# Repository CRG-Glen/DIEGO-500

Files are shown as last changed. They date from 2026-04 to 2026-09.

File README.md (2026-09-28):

# DIEGO PROJECT

Turn your A500 into an A2000 with this sidecar backplane
CHECKMATE VERSION NOT YET TESTED - DO NOT BUILD

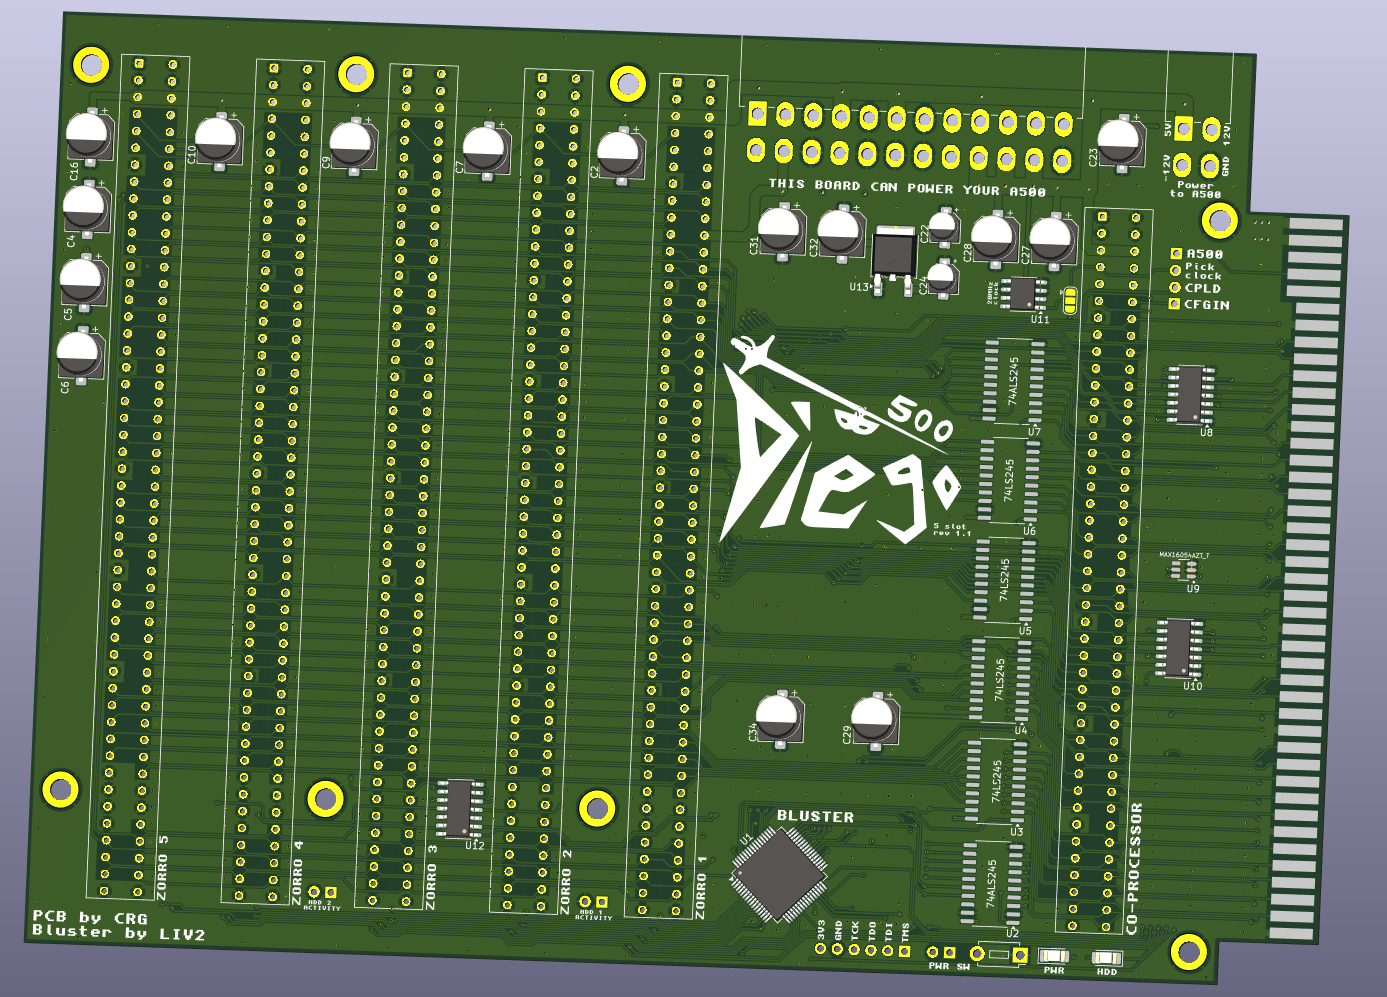
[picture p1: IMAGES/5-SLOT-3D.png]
PCB


## What's this?  

DIEGO is a Zorro 2 backplane expansion for use on your A500 either as a side car project or within your Checkmate case.  Diego gives you an A2000 compatible CO-PROCESSOR slot (side car version only) along with a full set of 5 ZORRO2 slots all made possible by the onboard Bluster IC.  Bluster is a remake of the classic A2000 Buster chip by LIV2 although it is a custom version for DIEGO to handle inverted clocks and provide some further functions.  

DIEGO has been tested extensively with various CPU and Zorro cards, a list of tested cards is provided below.  If you have anything to add to this list, please get in touch.  

DIEGO is also intended to power your A500 via the passthrough 4 pin connector adjacent to the main 24 pin ATX connector.  Please note that on the Checkmate version has power connected at the side car but also space for a passthrough.  The side car version currently does not have power connected at the side car.  For this version you must use the pass through to power your A500.  

## Ordering

There are currently 3 versions of DIEGO, a side car 5 slot version, a side car 3 slot version and a version for installation within a Checkmate case.  Please note that at present both the 3 slot and checkmate versions have not been tested so build at your own risk.  Checkmate version is currently in testing, I do not recommend building until it's confirmed working and ready.  

Gerber, BOM and CPL files are provided for each in the JLCPCB folder.  

All passives on each version are located on the bottom side (with exception of ferrite bead on checkmate version).  All logic and electrolytic caps are located on the top side.  

Each version of DIEGO is a 4 layer board.  HASL finish is fine for this project, inner layers can be left 0.5oz.  

All signals are routed on the top and bottom layers but there are some power traces on each internal layer along with solid grounds.  

Due to the amount of passives I recommend having your PCB manufacturer fit the bottom side, you then as builder complete the top side.  

While all components are available at JLC several top side parts are getting expensive!  

## Assembly

Assuming you got your boards made with the bottom side completed you may fit out the top side to suit yourself.  I recommend fitting and programming the CPLD first and finish all SMD work before doing the slots as they'll just get in the way!  

NOTE (side car version only): U11 is only required if you're using something in the COPROCESSOR slot that needs a 28mhz clock.  There doesn't seem to be that many (if any) cards that do require this so you may leave this off if you prefer. (this has not been tested as I don't have anything that needs this clock)

FURTHER NOTE: You MUST use LS and ALS logic as per the BOM.  DIEGO was originally built with HCT logic but this caused issues with several boards.  HCT will work if you prefer to use this but you might find some early SCSI cards don't work.  

For the 86pin slot to the A500 on the side car version you will need to bend the pins in to meet the pads on DIEGO.  

For programming the CPLD, the required JED file is available in the CPLD folder or you may get it from LIV2s GitHub.  I use a Raspberry PI to programme CPLDs as per LIV2s guide but use whatever method you're comfortable with.  Just remember if using a PI and if powering 3.3v from the PI, disconnect all other power supplies from DIEGO 500!

## Using your DIEGO

For the most part DIEGO is simply plug and play but there are a few things to keep in mind.
- Firstly there is a single jumper to configure to select which 7mhz clock to use.  If you're using a Rev3 or 5 A500 you must select CPLD clock.  If you're using a Rev6 A500 you can use either but if using A500 clock you need to close JP6 on the A500s motherboard.  If you are using an A500+ you can pick either.  The CPLD clock is derived from _CCK XNOR _CCQK within the CPLD.    
- There is one more pin header labelled CFGIN.  If you have any expansions in your A500 on the autoconfig chain you MUST connect said expansions config out to this config in.  If you don't you'll most likely get a yellow screen or just no zorro cards detected!
- Insert all cards as if this was a real A2000 i.e. the front of DIEGO is the front of an A2000.  Most modern Zorro expansions (especially half length cards) will have an arrow pointing to front or back.  Pay attention to this! If you plug something in wrong expect a dead card and possibly dead Amiga! 
- Zorro 2 cards will autoconfigure themselves just like they would in any Amiga.  To confirm this hold both mouse buttons on start up to access the early start-up menu and select "expansion board diagnostic" (only available to kickstart 2.04 and up)

Side car version only
-  If you're using a true A2000 CPU card in the COPROCESSOR slot (like the N2630) simply insert the card and Bluster will tristate the internal A500 CPU. (this is achieved by Bluster monitoring _BOSS and when asserted, Bluster asserts _BR to the internal CPU)  
- If you are using an A500 type accelerator in the COPROCESSOR slot such as TF536 or a PISTORM (including PISTORM 2000), you MUST open the A500 and remove the internal CPU.  Even if you manually assert _BOSS, the E clocks will clash and it won't work.  There is NO fix for this!  A2000 accelerators work as they monitor E and sync to it or generate it as necessary.  

Checkmate version only
- If you're using an accelerator in the A500s CPU socket you may need to connect its config out to the config in pin on DIEGO.  If you get a yellow screen or crash on boot this is the likely cause.  

## Testing and Results

With thanks to GADGETUK, SPARX, CATHERS and ANDI@HBR we've been able to test and confirm that most boards 
work fine in DIEGO.  The below table lists those boards tested and confirmed as working or not.

| Card Type | Name | Status |
|---|---|---|
| SCSI | Commodore A2090A | Working but very fussy (requires LS and ALS logic).  Only bluescsi V2 and only in raw mode. |
| SCSI | Commodore A2091 | Working |
| SCSI | GVP Series II HC+8 | Working |
| IDE |	Ripple IDE | Working |
| IDE |	AT-Bus clone | Working |
| IDE |	Buddha | Working |
| RAM |	Amigakit ZORRAM | Working |
| RAM |	Gottagofastram 2000 | Working |
| Sound | Prelude | Working |
| RTG |	GBAPII | Working |
| Multi-feature | LAN-IDE-Clock | Working/Working/Not tested |
| CPU |	A2630 | Working |
| CPU |	N2630 | Working |
| CPU |	TF520 | Working |
| CPU |	TF536 | Working |
| CPU |	TK2 | Working |
| CPU |	Pistorm | Working |
| CPU |	Pistorm 2k | Working |

If you can add to this table please get in touch!

## Case

At present there is no full case but there is a base that will hold either the 3 or 5 slot version of Diego level with the side car slot of your A500.  I'm not great at designing these things so if you want to help please get in touch.  STL files are in the BASE folder.  

## FAQ

Several people have asked about adding ISA slots, a video slot or making this remote with a ribbon cable to the A500.  

ISA slots - DIEGO side car has been designed so that you could in theory add ISA slots on a separate board, the Zorro slots 
in relation to the edge of the PCB are positioned to allow this.  I haven't designed an ISA slot extension as I don't have a bridge board to test it with.  
The Checkmate version could be redesigned to incorporate ISA slots although you will loose 2 of the half length zorro slots.  For this release it was thought more useful to include 5 zorro slots. 

Video slot - There are no plans to add a video slot.  Very few of the required signals are on the A500s side car so it would need a multicore ribbon from DENISE.  

Ribbon Cable for remote use - If you want to try a ribbon cable to have DIEGO remote from your 500 you can simply solder one onto the edge connector but I don't expect this to work without further buffering! (like in the bodega bay).

A1000 version - This is coming along with a rework of the entire project to sit vertical beside your 500.  It'll take a while to figure out so please bear with me.  

## License

This project represents countless hours of work by not just me but LIV2 and everyone involved in testing.  It is however released under a CERN Open Hardware Licence v2 for the community to enjoy.  

While I cannot put any direct stipulations into this I would ask that it should only be built and sold at cost plus time.  

If you plan on forking or using this as the basis for any other works you must comply with the following as per the terms of the license attributed to this project.
1. All attributions and credits as presented within this github and on the DIEGO 500 PCB must be maintained and carried through.
2. Any derivative of this project must be also be released open source.

If you are doing a build of these please consider a £1 donation per board to my kofi - https://ko-fi.com/crg_glen.  I'm at least £500 into this project so any support to recoup this is appreicated.  

## Credits

Based on A2000 rev6 schematics by Dave Haynie and EATX2000 by Jasonsbeer

PCB by CRG(Glen)

Bluster by LIV2

Artwork by Brick Studios

Testing by GadgetUK, Sparx, Cathers and Andi@HBR

Thanks to Mikerochip for inspiration for the PSU switch, Neil from Retro4U for loaning his GVP for testing and Kazanoz for helping with the BOM

Special thanks to GadgetUK for hosting the test room on his discord and LIV2 for his work modifying Bluster

Extra Special thanks to Rob Cranley and Steve Jones for their help on the Checkmate version

Why is it called Diego?  Well... this project started solely as a Zorro 2 expansion and to implement that I first had
to understand how the Zorro bus worked.  You might say I had to unmask Zorro.  The character of Zorro unmasked is called Don Diego so Diego 500 or Diego Checkmate.

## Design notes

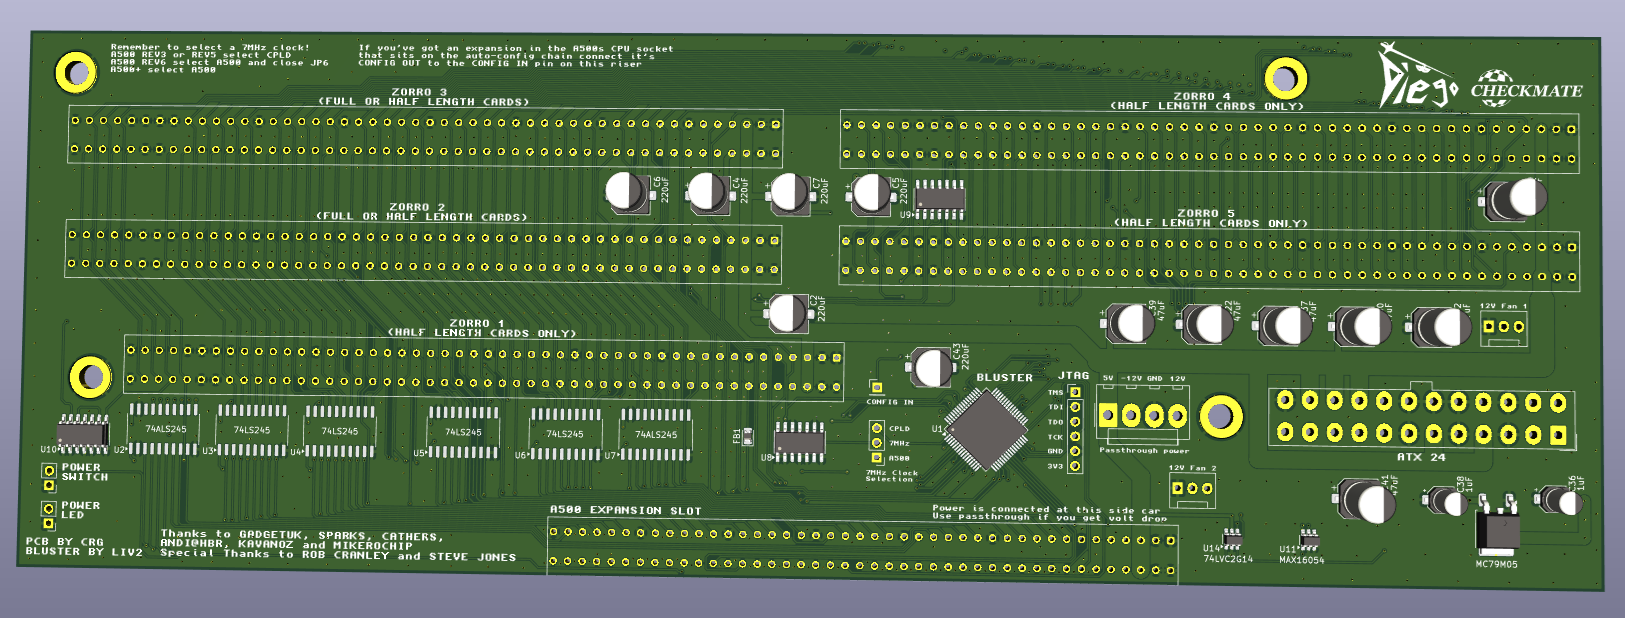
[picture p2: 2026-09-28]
JLCPCB/Checkmate/IMAGES/Checkmate-3D.png

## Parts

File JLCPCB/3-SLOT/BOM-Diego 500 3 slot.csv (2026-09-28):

Comment | Designator | Footprint | LCSC | Quantity
0.1uf | C1,C11,C12,C13,C14,C15,C17,C18,C19,C20,C21,C3,C30,C33,C8 | C_0805_2012Metric | C49678 | 15
1000pf | CN10,CN11,CN12,CN13,CN14,CN15,CN16,CN17,CN7,CN8,CN9 | R_Array_Convex_4x0603 | C541606 | 11
100pf | C25,C26 | C_0805_2012Metric | C1790 | 2
10k | R11,R12,R13,R18,R19,R20,R21,R22 | R_0805_2012Metric | C17414 | 8
1k | R1,R14,R17,R2,R24,R27,R28,R29,R38,R39,R40,R41,R5,R6 | R_0805_2012Metric | C17513 | 14
1k | RN1,RN10,RN11,RN12,RN13,RN14,RN15,RN16,RN17,RN18,RN19,RN2,RN20,RN8,RN9 | R_Array_Convex_4x0603 | C20197 | 15
1uF | C22,C24 | CP_Elec_4x5.4 | C3348 | 2
220uF | C2,C34,C4,C5,C6,C7,C9 | CP_Elec_6.3x7.7 | C278407 | 7
3.3k | RN3,RN4,RN5,RN6 | R_Array_Convex_4x0603 | C102665 | 4
3.3k | R10 | R_0805_2012Metric | C26010 | 1
33 | R3 | R_0805_2012Metric | C17634 | 1
4.7k | R25,R26,R7,R9 | R_0805_2012Metric | C17673 | 4
4.7k | RN7 | R_Array_Convex_4x0603 | C66697 | 1
47 | R16,R23,R4 | R_0805_2012Metric | C17714 | 3
47uF | C23,C27,C28,C29,C31,C32 | CP_Elec_6.3x7.7 | C336249 | 6
501MLFT | U11 | SOIC-8_3.9x4.9mm_P1.27mm | C2651221 | 1
680 | R15 | R_0805_2012Metric | C17798 | 1
74ALS245 | U2,U7 | SO-20_5.3x12.6mm_P1.27mm | C2675885 | 2
74LS08 | U10 | SO-14_3.9x8.65mm_P1.27mm | C6802 | 1
74LS245 | U3,U4,U5,U6 | SO-20_5.3x12.6mm_P1.27mm | C7753 | 4
74LS32 | U12,U8 | SO-14_3.9x8.65mm_P1.27mm | C116812 | 2
A2000_CPUSLOT_EDGE_LOGICAL | J2 | WingTAT ED86BGFBK | C5173317 | 1
BLUSTER | U1 | TQFP-64_10x10mm_P0.5mm | C90569 | 1
FerriteBead_Small | FB1 | D_0805_2012Metric 100ohm @ 100mhz | C15957 | 1
LED | D2 | LED_1206_3216Metric_Pad1.42x1.75mm_HandSolder | C14641 | 1
LED | D1 | LED_1206_3216Metric_Pad1.42x1.75mm_HandSolder | C49018 | 1
MAX16054AZT_T | U9 | SOT95P275X110-6N | C79401 | 1
MC79M05 | U13 | TO-252-2 | C126401 | 1
S8050 | Q1 | SOT-23 | C2146 | 1
Zorro 1 | CN2 | WingTAT ED100BGFBK | C5173320 | 1
Zorro 2 | CN3 | WingTAT ED100BGFBK | C5173320 | 1
Zorro 3 | CN4 | WingTAT ED100BGFBK | C5173320 | 1
Conn_01x01_Pin | J9 | PinHeader_1x01_P2.54mm_Vertical |  | 1
Power to A500 | J8 | Molex_Mini-Fit_Jr_5569-04A2_2x02_P4.20mm_Horizontal |  | 1
Conn_01x03_Pin | J1 | PinHeader_1x03_P2.54mm_Vertical |  | 1
Conn_01x02_Pin | J5 | PinHeader_1x02_P2.54mm_Vertical |  | 1
HDD 2 | J3 | PinHeader_1x02_P2.54mm_Vertical |  | 1
Buster | J7 | PinHeader_1x06_P2.54mm_Vertical |  | 1
A500 side car | CN1 | A500_SIDE_CONNECTOR |  | 1
ATX-24 | J6 | Molex_Mini-Fit_Jr_5569-24A2_2x12_P4.20mm_Horizontal |  | 1
SW_Push | SW1 | SW_PUSH_1P1T_6x3.5mm_H4.3_APEM_MJTP1243 |  | 1
HDD 1 | J4 | PinHeader_1x02_P2.54mm_Vertical |  | 1

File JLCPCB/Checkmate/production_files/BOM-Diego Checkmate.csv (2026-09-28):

Comment | Designator | Footprint | LCSC | Quantity
0.1uf | C1,C11,C12,C13,C14,C15,C16,C17,C18,C19,C20,C21,C3,C30,C35,C8,C9 | C_0805_2012Metric | C49678 | 17
1000pf | CN10,CN11,CN12,CN13,CN14,CN15,CN16,CN17,CN7,CN8,CN9 | R_Array_Convex_4x0603 | C541606 | 11
100pf | C25,C26 | C_0805_2012Metric | C1790 | 2
10k | R18,R19,R20,R21,R22,R3 | R_0805_2012Metric | C17414 | 6
1k | R1,R11,R12,R13,R14,R15,R17,R2,R24,R27,R28,R29,R30,R5,R6,R8 | R_0805_2012Metric | C17513 | 16
1k | RN1,RN10,RN11,RN12,RN13,RN14,RN15,RN16,RN17,RN18,RN19,RN2,RN8,RN9 | R_Array_Convex_4x0603 | C20197 | 14
1uF | C36,C38 | CP_Elec_4x5.4 | C3348 | 2
220uF | C10,C2,C4,C43,C5,C6,C7 | CP_Elec_6.3x7.7 | C278407 | 7
3.3k | R10 | R_0805_2012Metric | C26010 | 1
3.3k | RN3,RN4,RN5,RN6 | R_Array_Convex_4x0603 | C425215 | 4
4.7k | R25,R26,R7,R9 | R_0805_2012Metric | C17673 | 4
4.7k | RN7 | R_Array_Convex_4x0603 | C66697 | 1
47 | R16,R23,R4 | R_0805_2012Metric | C17714 | 3
47uF | C22,C37,C39,C40,C41,C42 | CP_Elec_6.3x7.7 | C336249 | 6
74ALS245 | U2,U7 | SO-20_5.3x12.6mm_P1.27mm | C2675885 | 2
74LS08 | U10 | SO-14_3.9x8.65mm_P1.27mm | C6802 | 1
74LS245 | U3,U4,U5,U6 | SO-20_5.3x12.6mm_P1.27mm | C7753 | 4
74LS32 | U8,U9 | SO-14_3.9x8.65mm_P1.27mm | C116812 | 2
74LVC2G14 | U14 | SOT-23-6 | C12401 | 1
A500 side car | CN1 | Samtec_HLE-150-02-xx-DV-TE_2x43_P2.54mm_Horizontal | C5173317 | 1
BLUSTER | U1 | TQFP-64_10x10mm_P0.5mm | C90569 | 1
FerriteBead_Small | FB1 | D_0805_2012Metric | C1015 | 1
MAX16054 | U11 | SOT-23-6 | C79401 | 1
MC79M05 | U15 | TO-252-2 | C126401 | 1
S8050 | Q2,Q3,Q4 | SOT-23 | C2146 | 3
Zorro 1 | CN2 | Samtec_HLE-150-02-xx-DV-TE_2x50_P2.54mm_Horizontal | C5173320 | 1
Zorro 2 | CN3 | Samtec_HLE-150-02-xx-DV-TE_2x50_P2.54mm_Horizontal | C5173320 | 1
Zorro 3 | CN4 | Samtec_HLE-150-02-xx-DV-TE_2x50_P2.54mm_Horizontal | C5173320 | 1
Zorro 4 | CN5 | Samtec_HLE-150-02-xx-DV-TE_2x50_P2.54mm_Horizontal | C5173320 | 1
Zorro 5 | CN6 | Samtec_HLE-150-02-xx-DV-TE_2x50_P2.54mm_Horizontal | C5173320 | 1
Power LED | J4 | PinHeader_1x02_P2.54mm_Vertical |  | 1
Conn_01x04 | J2 | Molex_KK-396_A-41791-0004_1x04_P3.96mm_Vertical |  | 1
Fan 2 | M2 | FanPinHeader_1x03_P2.54mm_Vertical |  | 1
Conn_01x02_Pin | J3 | PinHeader_1x02_P2.54mm_Vertical |  | 1
ATX-24 | J10 | Molex_Mini-Fit_Jr_5566-24A_2x12_P4.20mm_Vertical |  | 1
Buster | J7 | PinHeader_1x06_P2.54mm_Vertical |  | 1
Conn_01x03_Pin | J1 | PinHeader_1x03_P2.54mm_Vertical |  | 1
Conn_01x01_Pin | J9 | PinHeader_1x01_P2.54mm_Vertical |  | 1
Fan 1 | M1 | FanPinHeader_1x03_P2.54mm_Vertical |  | 1

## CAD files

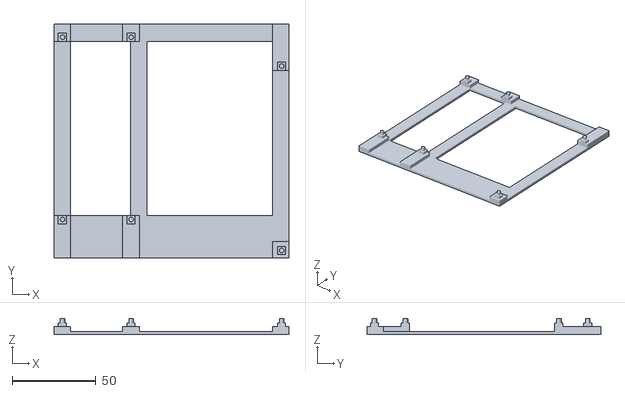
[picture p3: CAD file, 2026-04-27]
BASE/Diego 500 3 slot base.stl
140.5 x 140.0 x 9.75

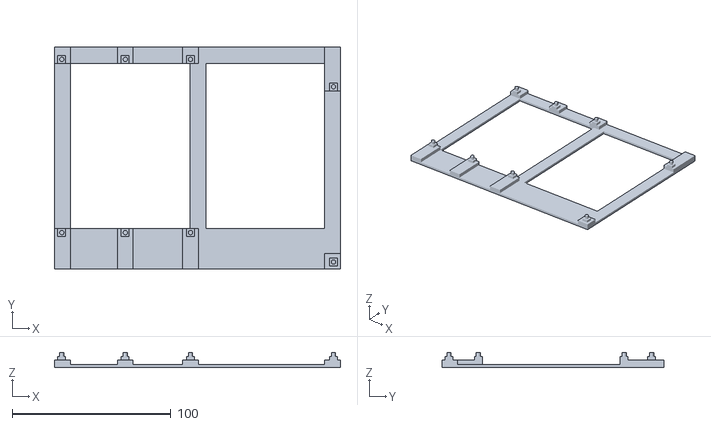
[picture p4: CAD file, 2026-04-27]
BASE/Diego 500 5 slot base.stl
180.0 x 140.0 x 9.75

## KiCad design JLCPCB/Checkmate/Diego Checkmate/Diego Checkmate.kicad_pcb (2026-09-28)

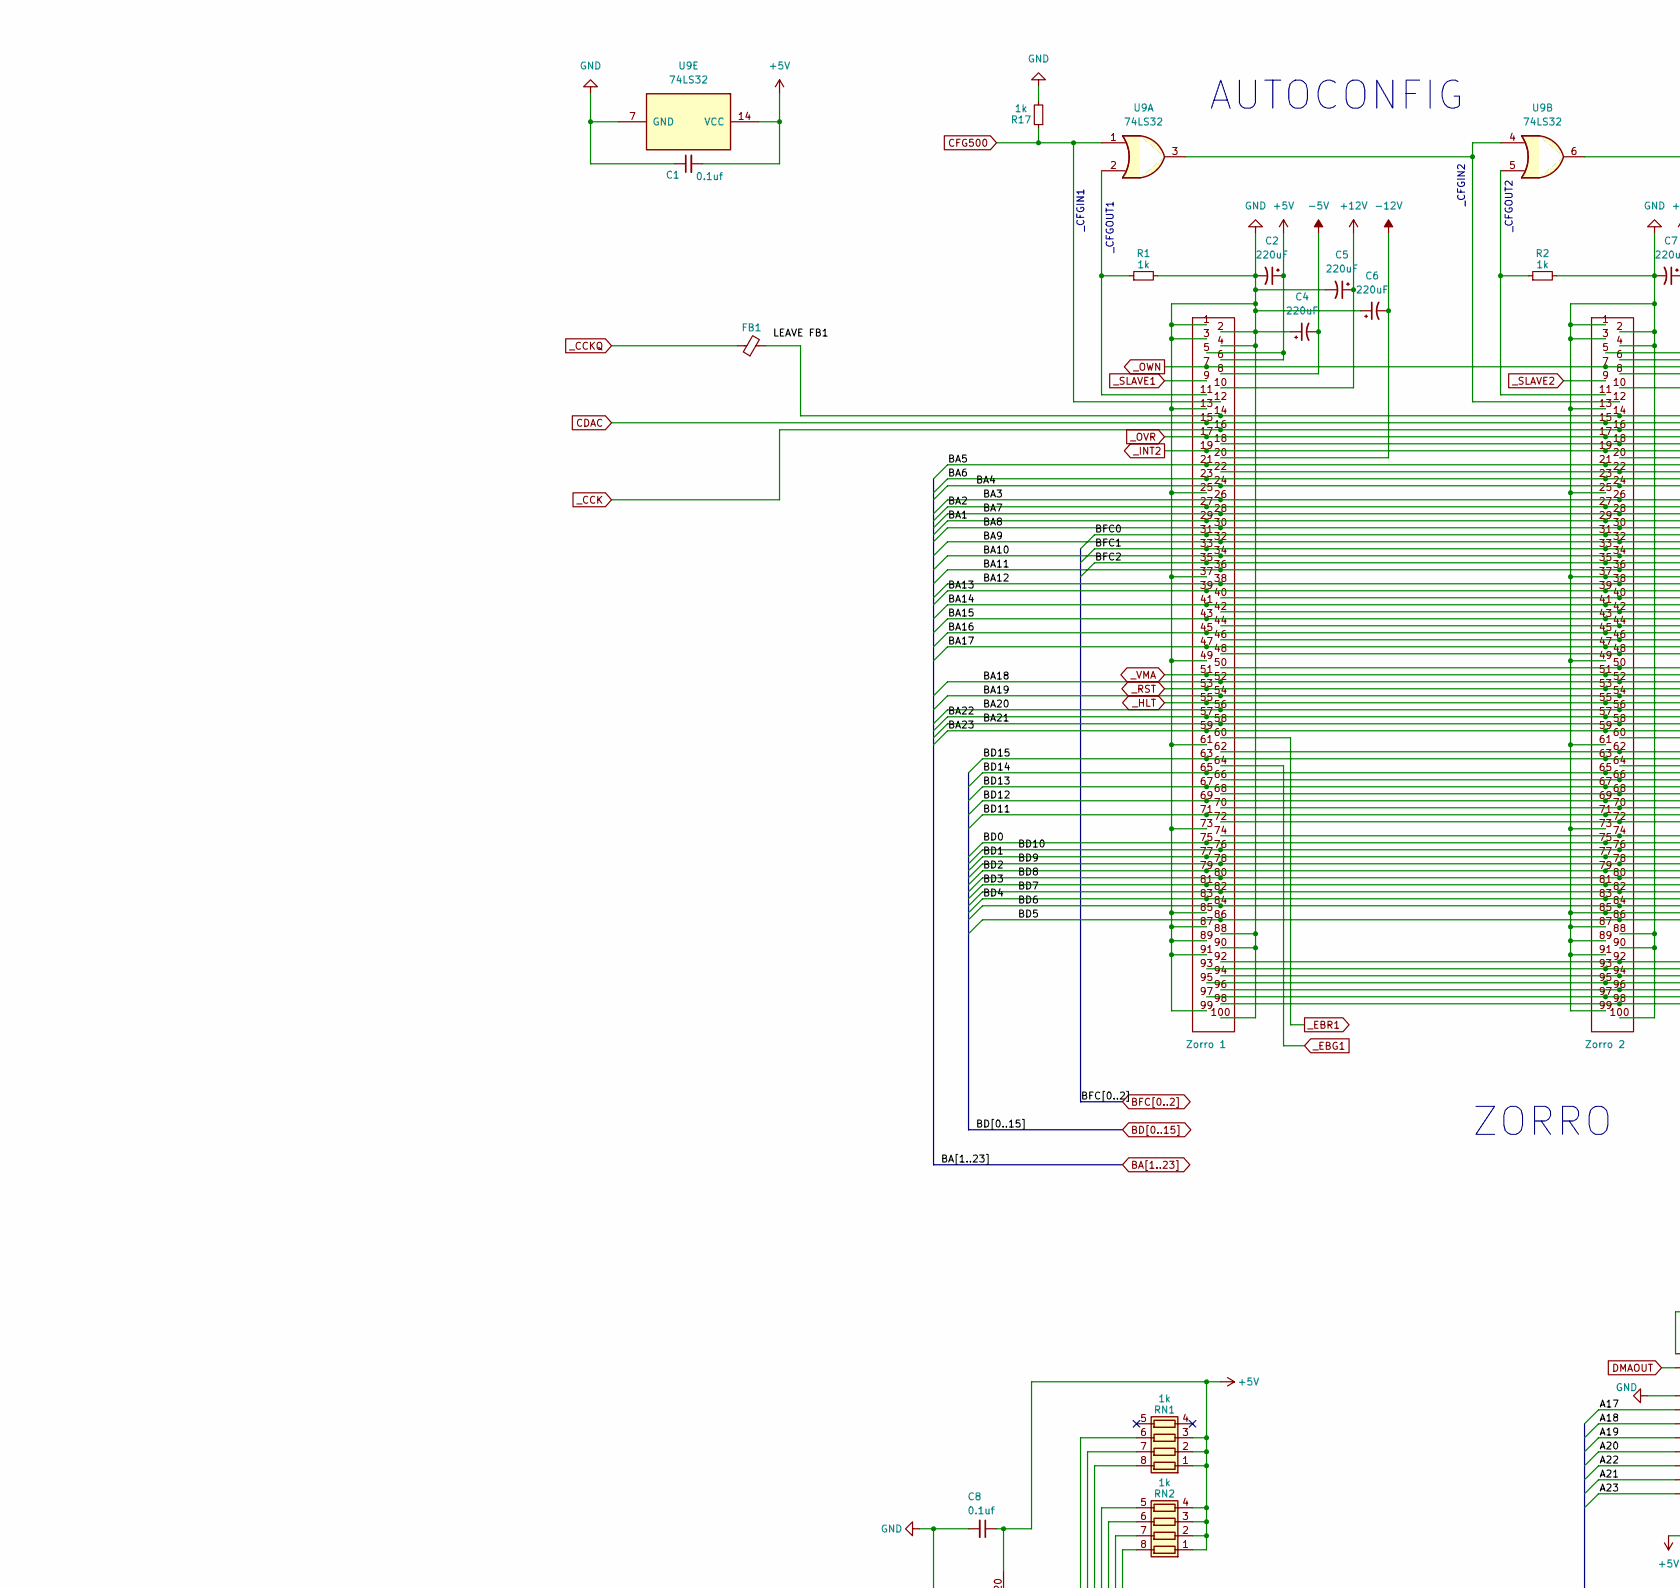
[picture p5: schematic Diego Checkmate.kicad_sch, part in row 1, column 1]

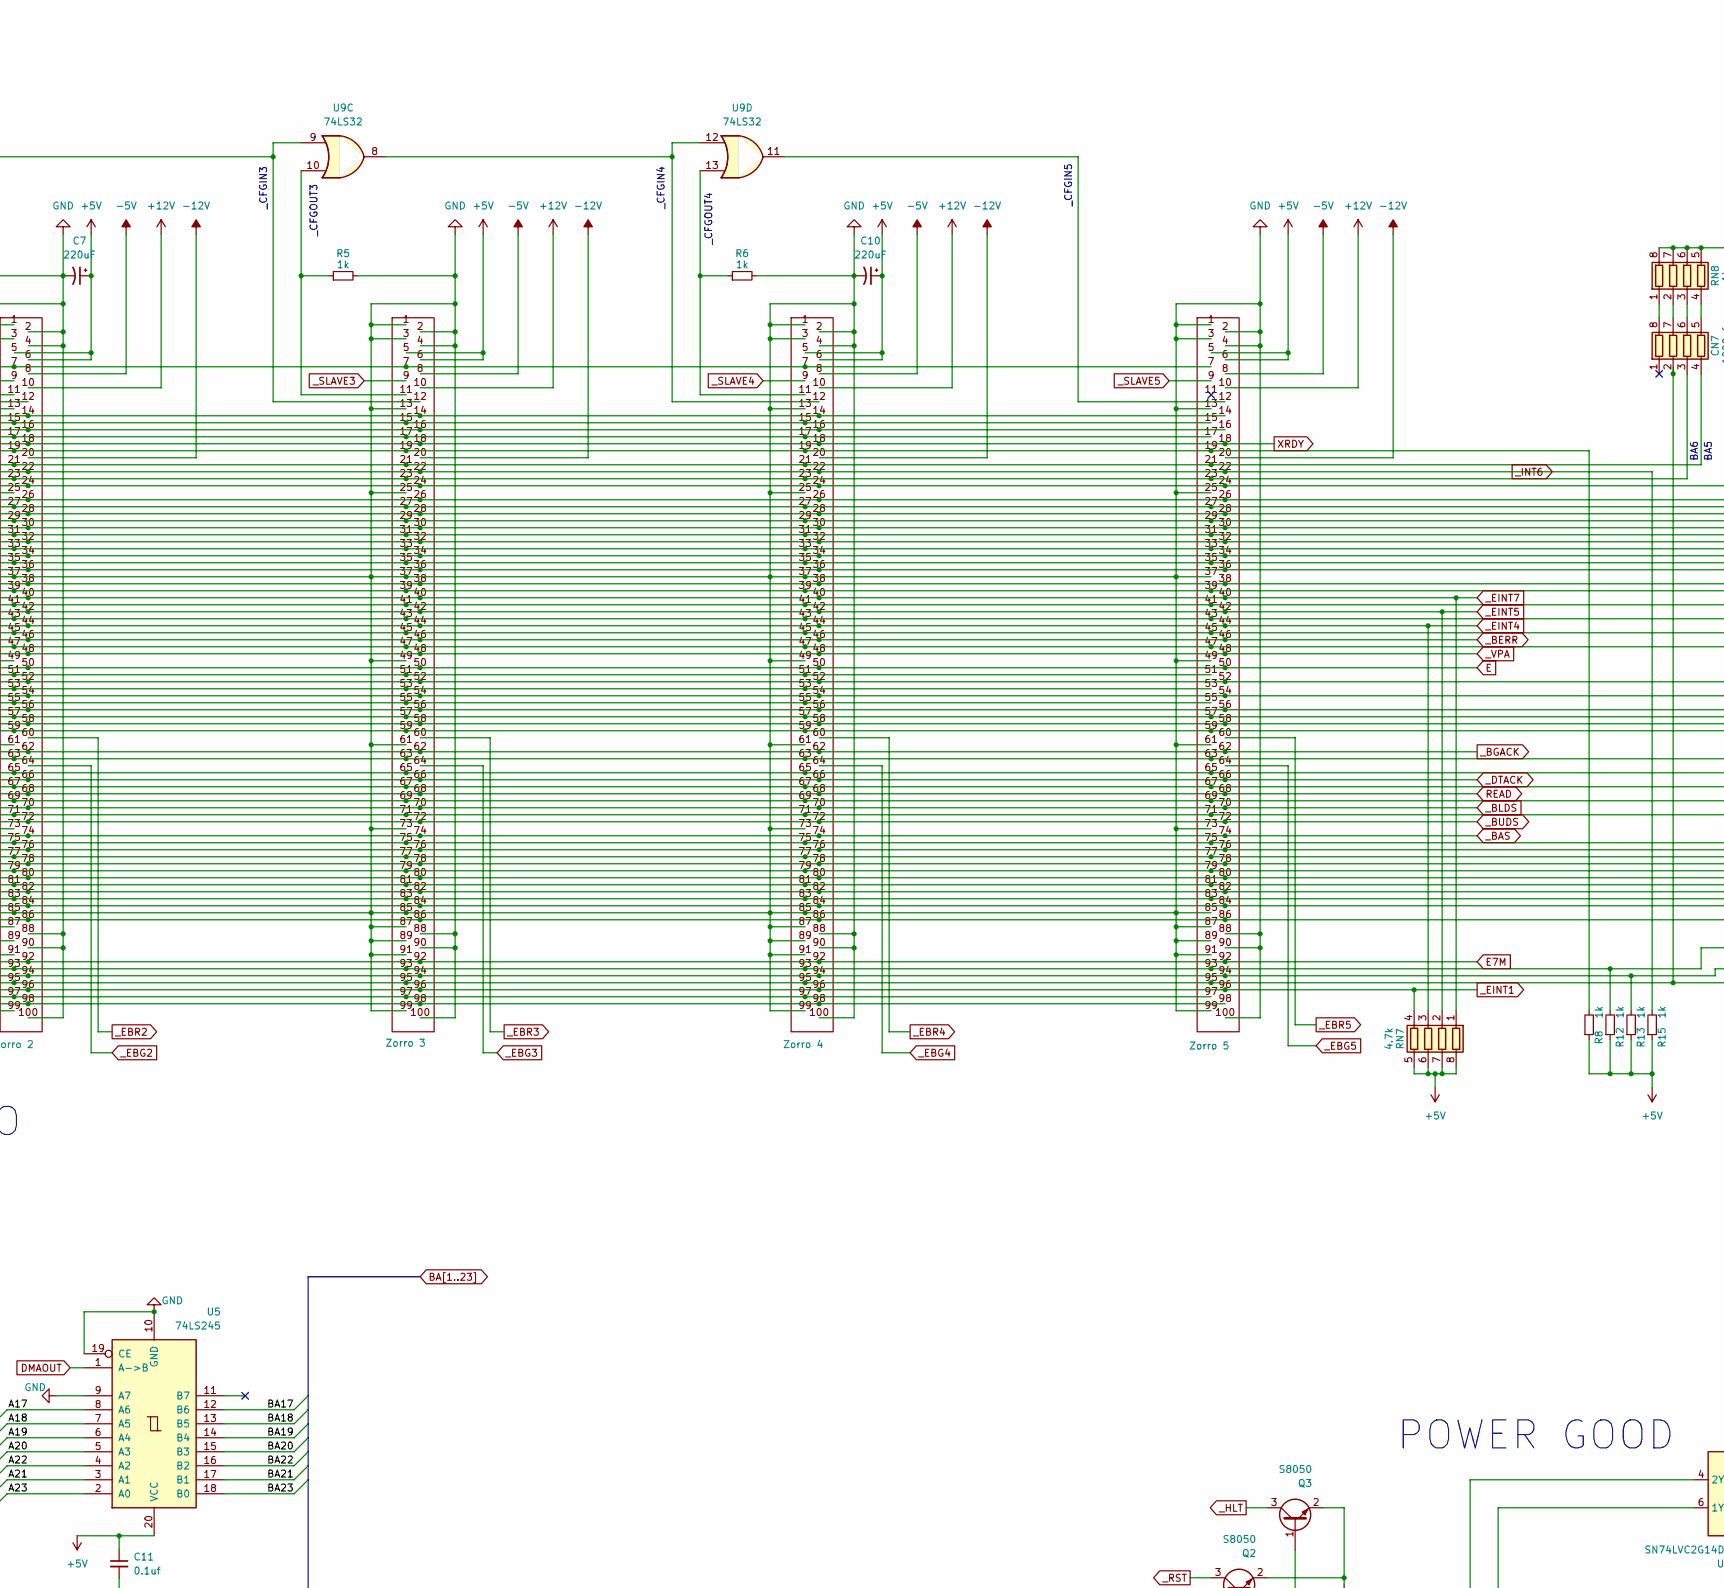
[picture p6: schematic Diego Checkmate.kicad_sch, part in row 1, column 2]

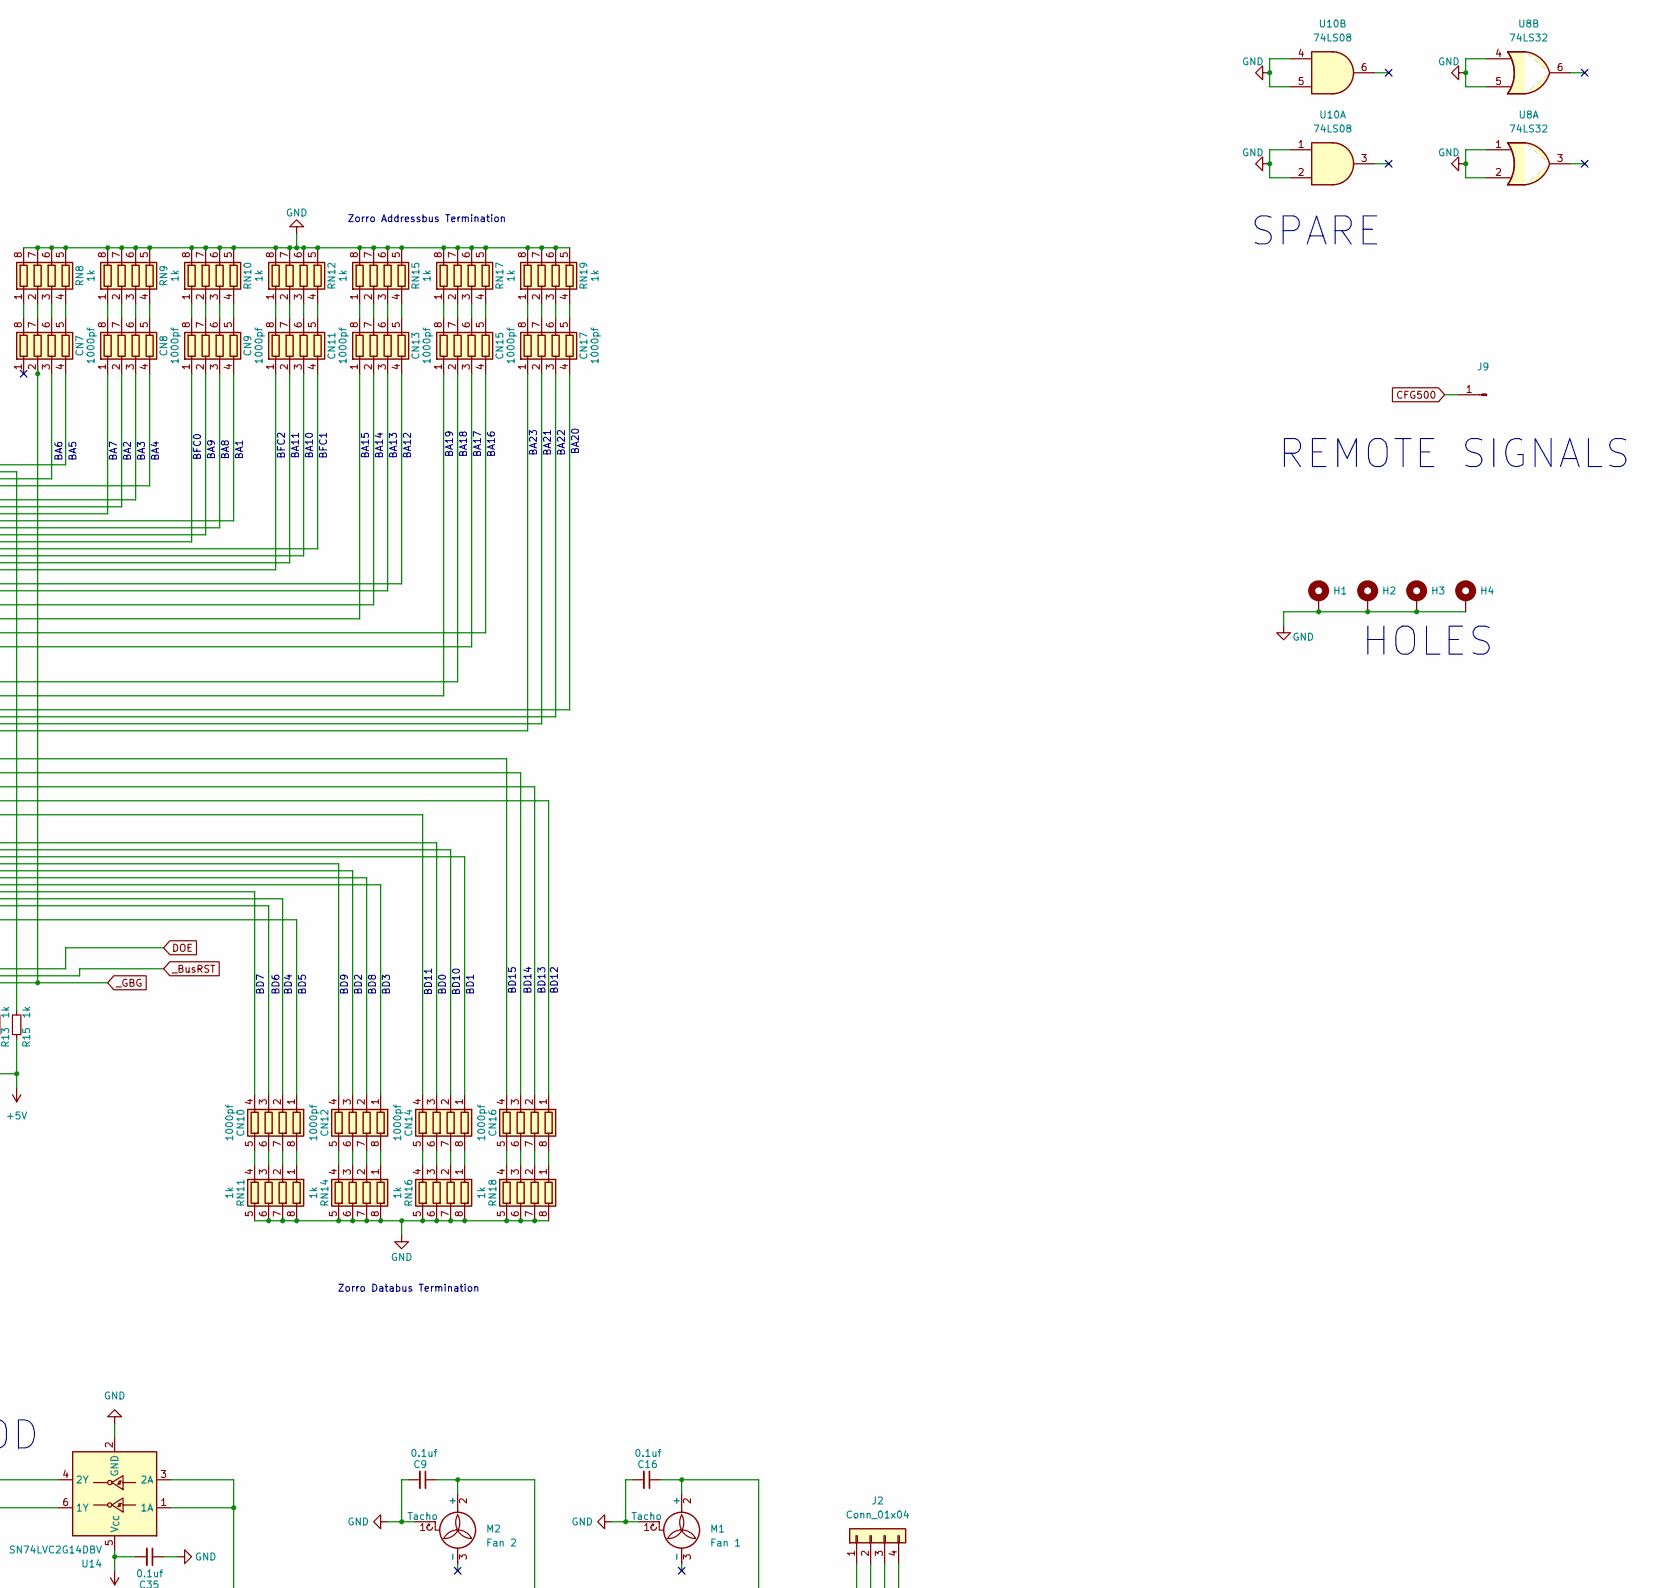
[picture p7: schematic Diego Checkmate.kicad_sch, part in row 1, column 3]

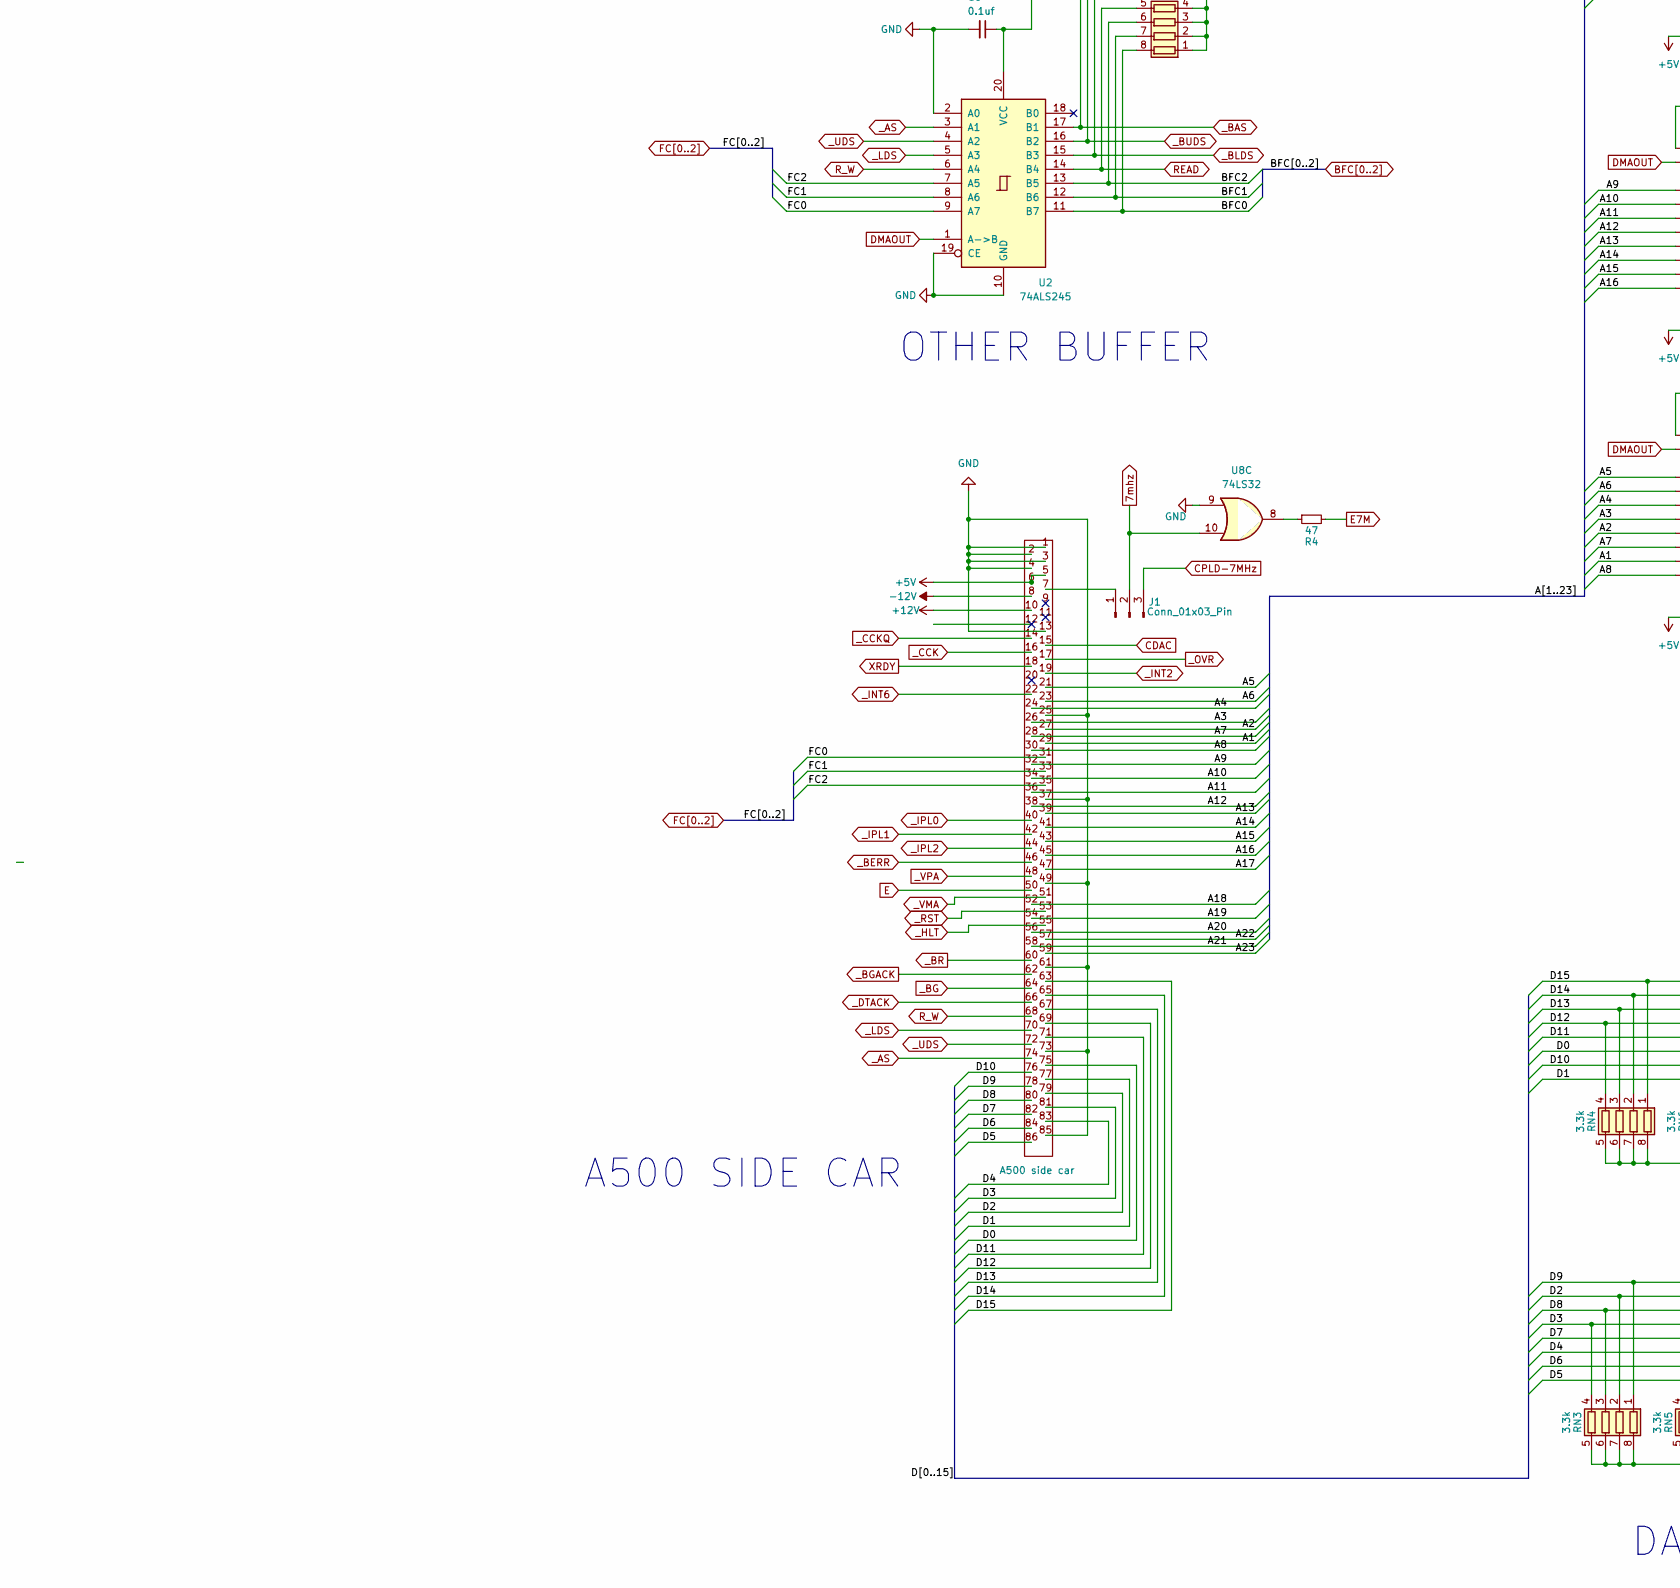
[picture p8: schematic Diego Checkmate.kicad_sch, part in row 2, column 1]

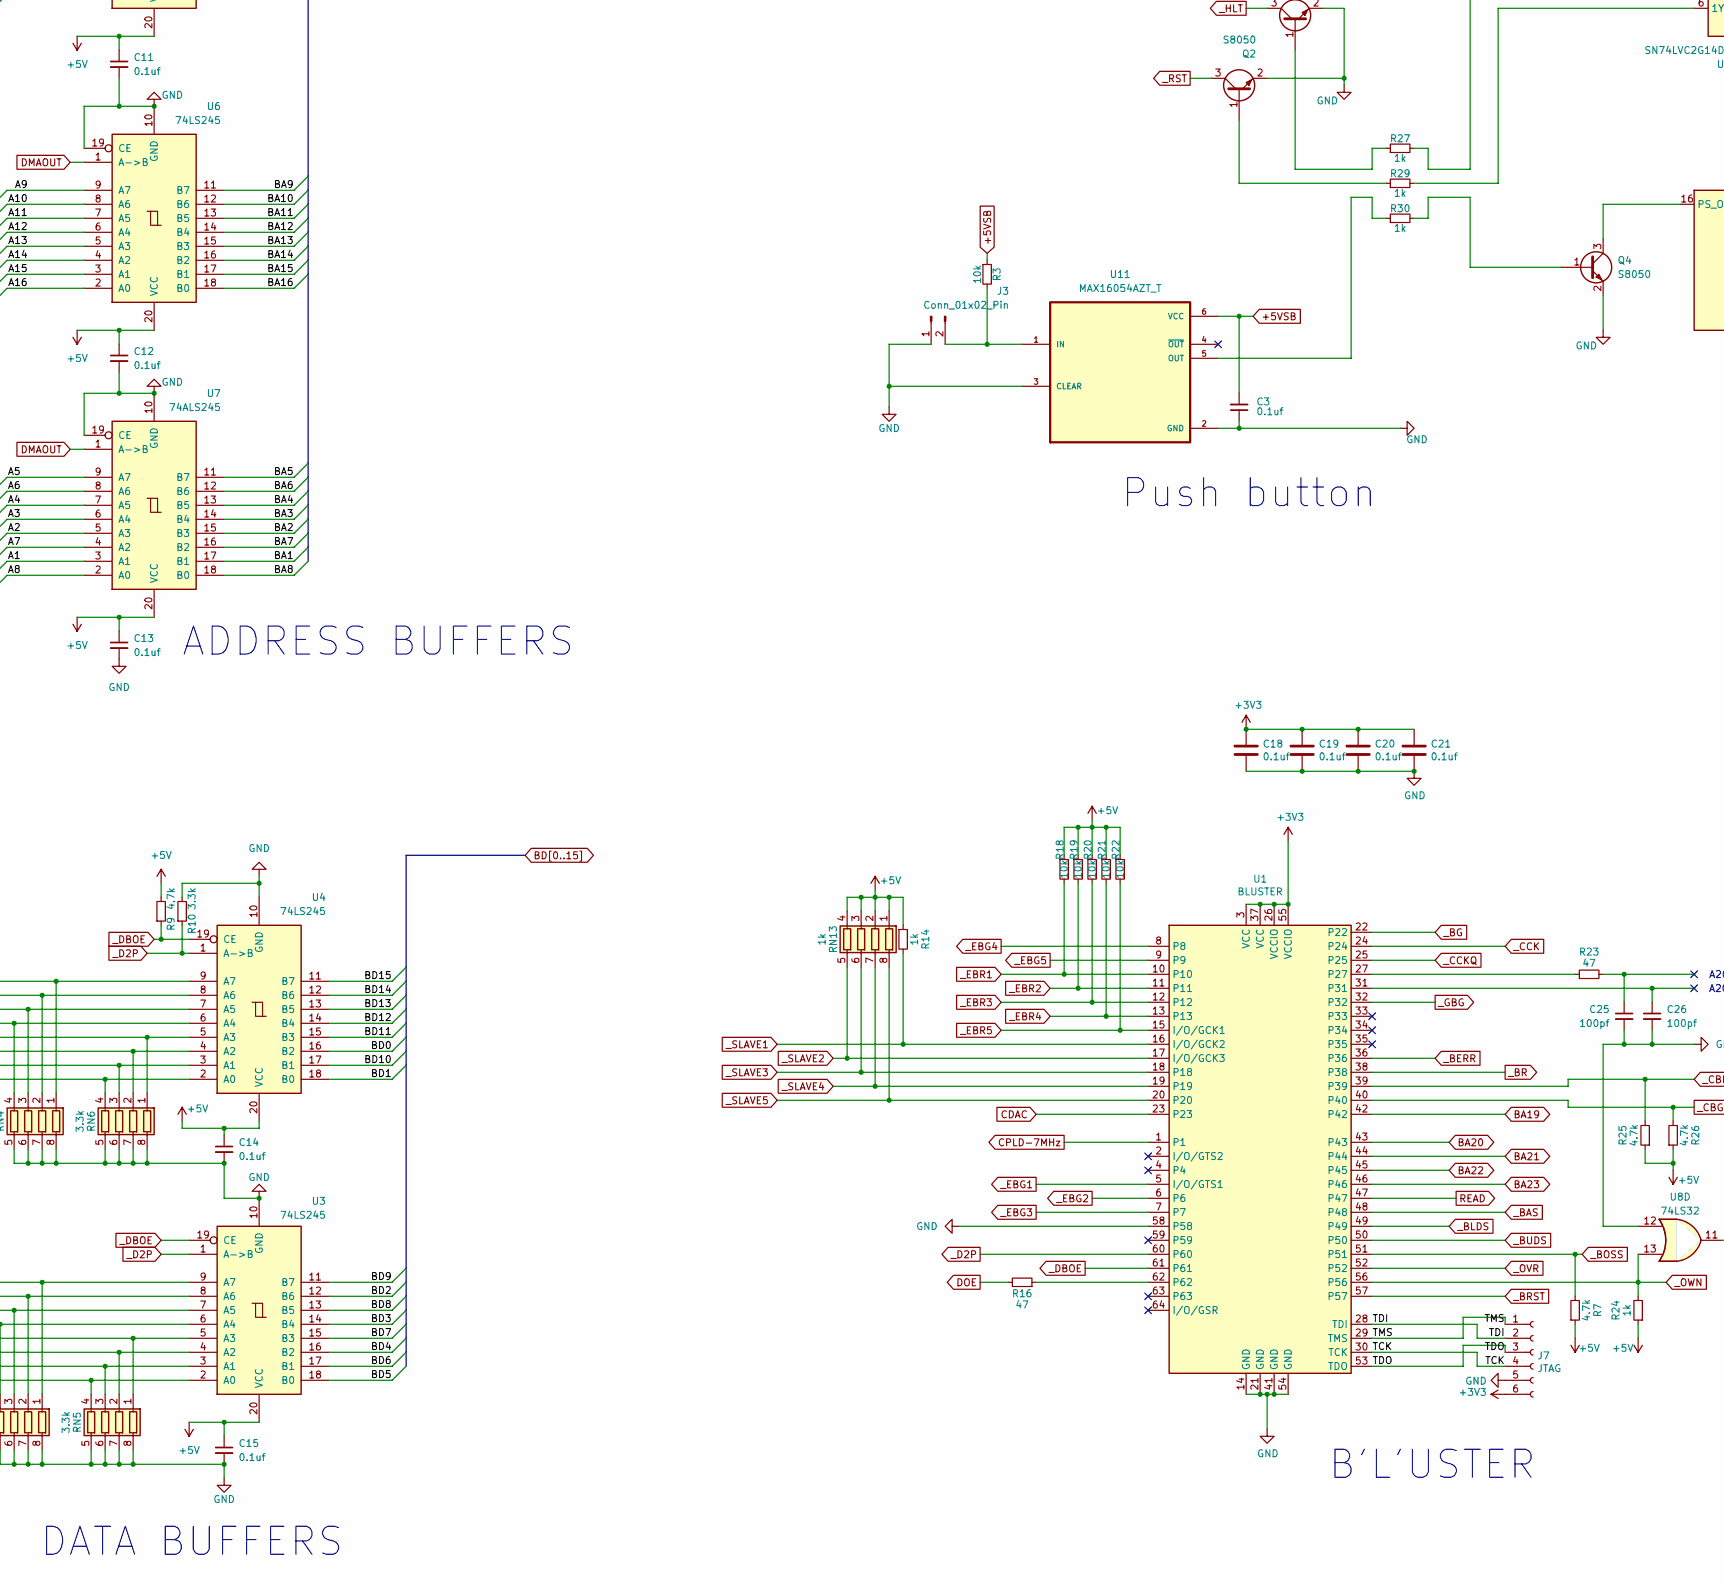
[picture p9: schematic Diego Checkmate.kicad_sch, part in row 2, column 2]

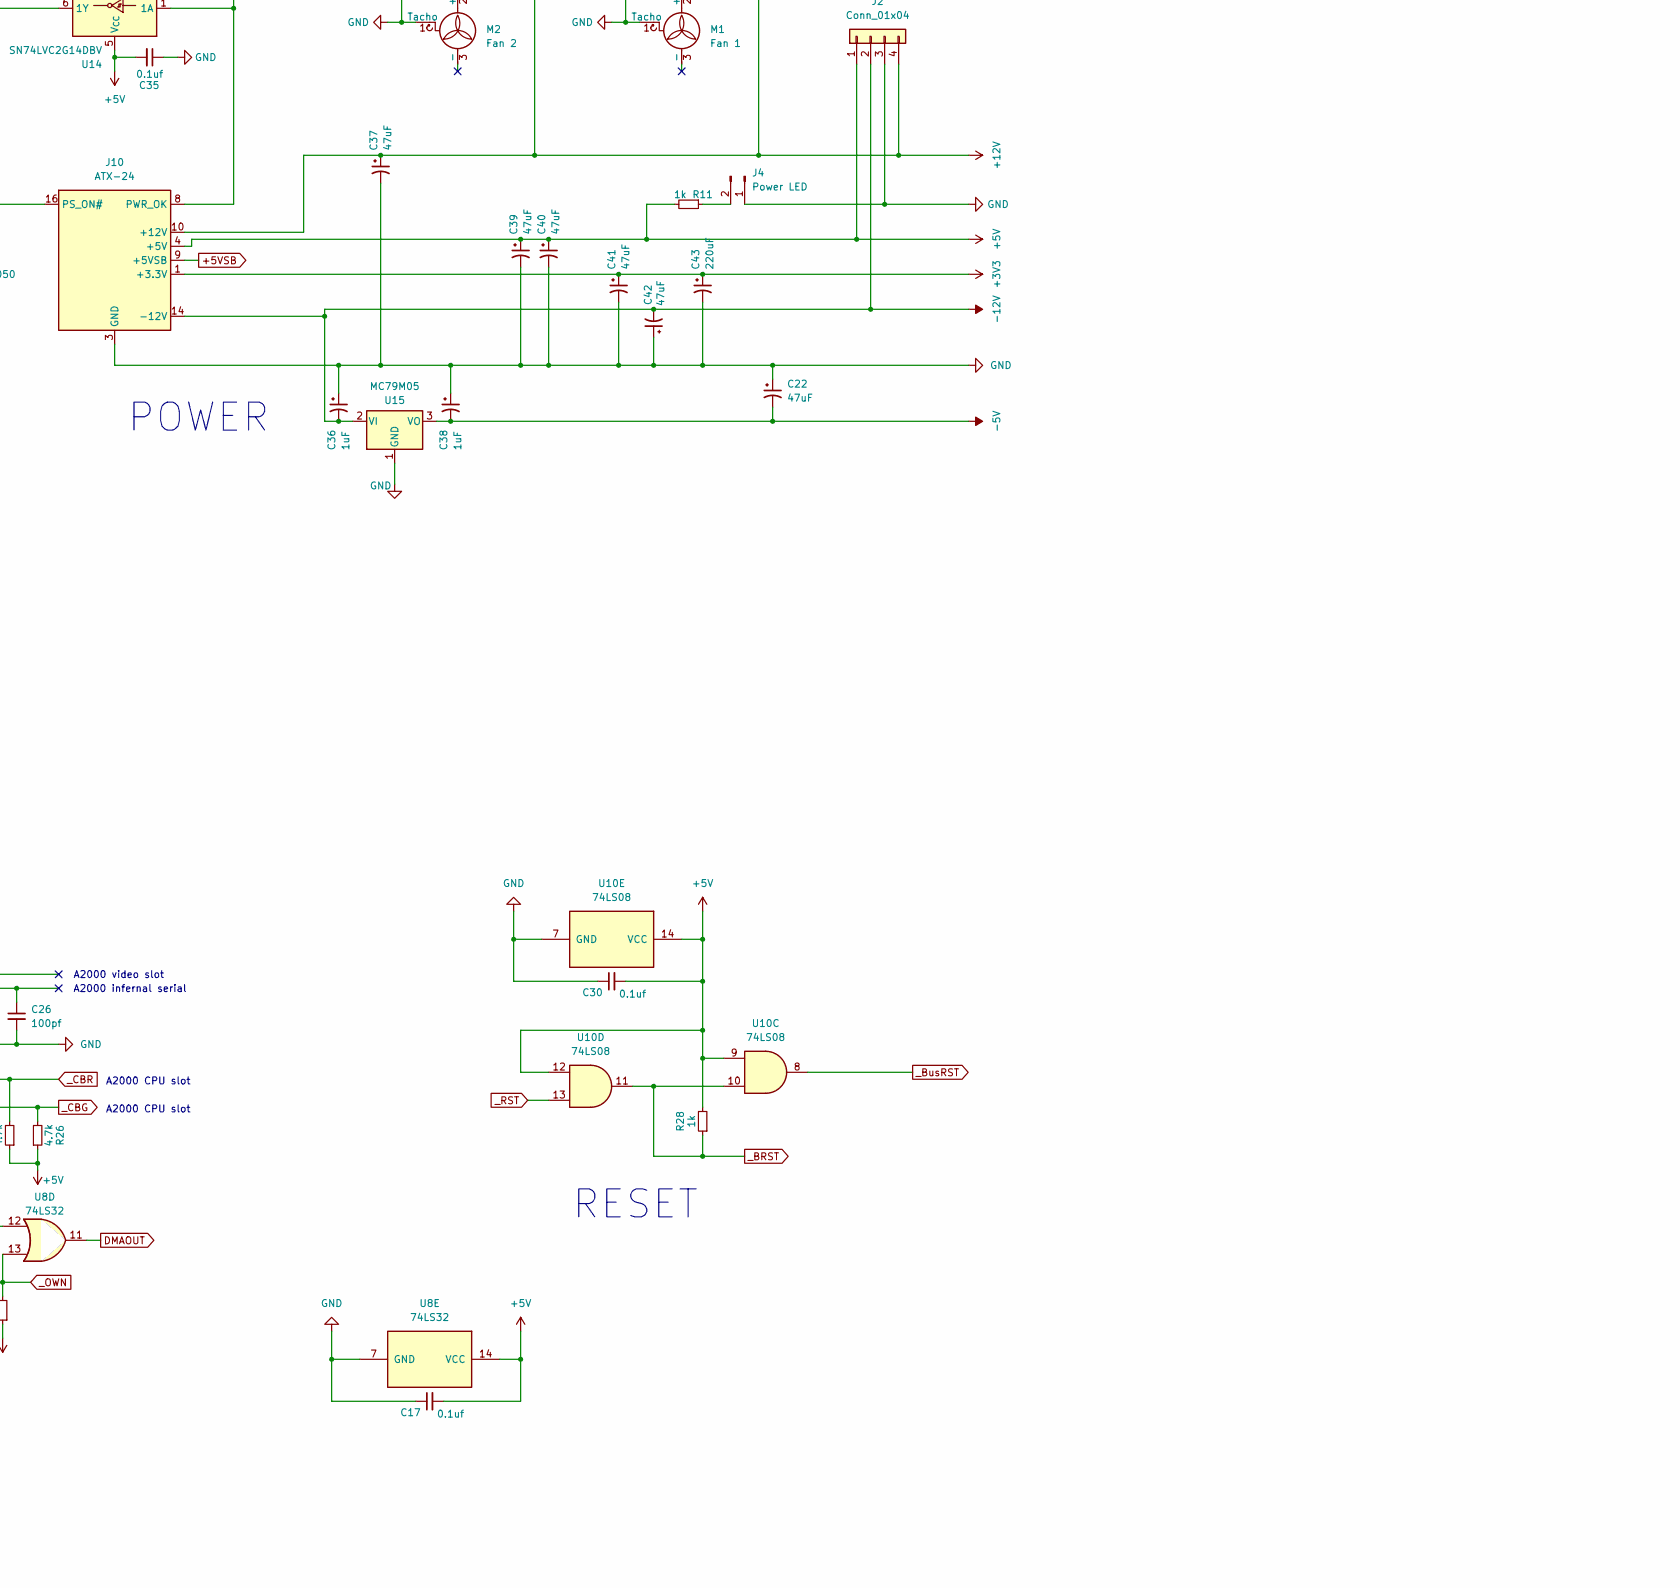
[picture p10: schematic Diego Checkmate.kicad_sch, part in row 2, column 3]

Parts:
C1, C3, C8, C9, C11, C12, C13, C14, C15, C16, C17, C30, C35: 0.1uf; C_0805_2012Metric; LCSC C49678
C2, C4, C5, C6, C7, C10, C43: 220uF; CP_Elec_6.3x7.7; LCSC C278407
C18, C19, C20, C21: 0.1uf; C_0805_2012Metric_Pad1.18x1.45mm_HandSolder; LCSC C49678
C22, C37, C39, C40, C41, C42: 47uF; CP_Elec_6.3x7.7; LCSC C336249
C25, C26: 100pf; C_0805_2012Metric; LCSC C1790
C36, C38: 1uF; CP_Elec_4x5.4; LCSC C3348
CN1: A500 side car; Samtec_HLE-150-02-xx-DV-TE_2x43_P2.54mm_Horizontal; LCSC C5173317
CN2: Zorro 1; Samtec_HLE-150-02-xx-DV-TE_2x50_P2.54mm_Horizontal; LCSC C5173320
CN3: Zorro 2; Samtec_HLE-150-02-xx-DV-TE_2x50_P2.54mm_Horizontal; LCSC C5173320
CN4: Zorro 3; Samtec_HLE-150-02-xx-DV-TE_2x50_P2.54mm_Horizontal; LCSC C5173320
CN5: Zorro 4; Samtec_HLE-150-02-xx-DV-TE_2x50_P2.54mm_Horizontal; LCSC C5173320
CN6: Zorro 5; Samtec_HLE-150-02-xx-DV-TE_2x50_P2.54mm_Horizontal; LCSC C5173320
CN7, CN8, CN9, CN10, CN11, CN12, CN13, CN14, CN15, CN16, CN17: 1000pf; R_Array_Convex_4x0603; LCSC C541606
FB1: FerriteBead_Small; D_0805_2012Metric; LCSC C1015
H1, H2, H3, H4: MountingHole_Pad; MountingHole_4.3mm_M4_DIN965_Pad_TopBottom
J1: Conn_01x03_Pin; PinHeader_1x03_P2.54mm_Vertical
J2: Conn_01x04; Molex_KK-396_A-41791-0004_1x04_P3.96mm_Vertical
J3: Conn_01x02_Pin; PinHeader_1x02_P2.54mm_Vertical
J4: Power LED; PinHeader_1x02_P2.54mm_Vertical
J7: JTAG; PinHeader_1x06_P2.54mm_Vertical
J9: Conn_01x01_Pin; PinHeader_1x01_P2.54mm_Vertical
J10: ATX-24; Molex_Mini-Fit_Jr_5566-24A_2x12_P4.20mm_Vertical
M1: Fan 1; FanPinHeader_1x03_P2.54mm_Vertical
M2: Fan 2; FanPinHeader_1x03_P2.54mm_Vertical
Q2, Q3, Q4: S8050; SOT-23; LCSC C2146
R1, R2, R5, R6, R8, R11, R12, R13, R14, R15, R17, R24, R27, R28, R29, R30: 1k; R_0805_2012Metric; LCSC C17513
R3, R18, R19, R20, R21, R22: 10k; R_0805_2012Metric; LCSC C17414
R4, R16, R23: 47; R_0805_2012Metric; LCSC C17714
R7, R9, R25, R26: 4.7k; R_0805_2012Metric; LCSC C17673
R10: 3.3k; R_0805_2012Metric; LCSC C26010
RN1, RN2, RN8, RN9, RN10, RN11, RN12, RN13, RN14, RN15, RN16, RN17, RN18, RN19: 1k; R_Array_Convex_4x0603; LCSC C20197
RN3, RN4, RN5, RN6: 3.3k; R_Array_Convex_4x0603; LCSC C425215
RN7: 4.7k; R_Array_Convex_4x0603; LCSC C66697
U1: BLUSTER; TQFP-64_10x10mm_P0.5mm; LCSC C90569
U2, U7: 74ALS245; SO-20_5.3x12.6mm_P1.27mm; LCSC C2675885
U3, U4, U5, U6: 74LS245; SO-20_5.3x12.6mm_P1.27mm; LCSC C7753
U8, U9: 74LS32; SO-14_3.9x8.65mm_P1.27mm; LCSC C116812
U10: 74LS08; SO-14_3.9x8.65mm_P1.27mm; LCSC C6802
U11: MAX16054AZT_T; SOT-23-6; LCSC C79401
U14: SN74LVC2G14DBV; SOT-23-6; LCSC C12401
U15: MC79M05; TO-252-2; LCSC C126401

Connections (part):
7mhz: J1.2, U8.10
+3V3: C18.1, C19.1, C20.1, C21.1, C41.1, C43.1, J7.6, J10.1 (+3.3V), J10.2 (+3.3V), J10.12 (+3.3V), J10.13 (+3.3V), U1.3 (VCC), U1.26 (VCCIO), U1.37 (VCC), U1.55 (VCCIO)
+5V: C1.2, C2.1, C7.1, C8.1, C10.1, C11.1, C12.1, C13.1, C14.1, C15.1, C17.2, C30.2, C35.2, C39.1, C40.1, CN1.5, CN1.6, CN2.5, CN2.6, CN3.5, CN3.6, CN4.5, CN4.6, CN5.5, CN5.6, CN6.5, CN6.6, J2.1, J10.4 (+5V), J10.6 (+5V), J10.21 (+5V), J10.22 (+5V), J10.23 (+5V), R7.1, R8.1, R9.2, R11.2, R12.1, R13.1, R14.1, R15.1, R18.1, R19.1, R20.1, R21.1, R22.1, R24.1, R25.1, R26.1, R28.2, RN1.1 (R1.1), RN1.2 (R2.1), RN1.3 (R3.1), RN2.1 (R1.1), RN2.2 (R2.1), RN2.3 (R3.1), RN2.4 (R4.1), RN7.5 (R4.2), RN7.6 (R3.2), RN7.7 (R2.2), RN7.8 (R1.2), RN13.1 (R1.1), RN13.2 (R2.1), RN13.3 (R3.1), RN13.4 (R4.1), U2.20 (VCC), U3.20 (VCC), U4.20 (VCC), U5.20 (VCC), U6.20 (VCC), U7.20 (VCC), U8.14 (VCC), U9.14 (VCC), U10.9, U10.12, U10.14 (VCC), U14.5 (V_{CC})
+5VSB: C3.2, J10.9 (+5VSB), R3.1, U11.6 (VCC)
+12V: C5.1, C9.1, C16.1, C37.1, CN1.10, CN2.10, CN3.10, CN4.10, CN5.10, CN6.10, J2.4, J10.10 (+12V), J10.11 (+12V), M1.2 (+), M2.2 (+)
-5V: C4.2, C22.2, C38.2, CN2.8, CN3.8, CN4.8, CN5.8, CN6.8, U15.3 (VO)
-12V: C6.2, C36.2, C42.2, CN1.8, CN2.20, CN3.20, CN4.20, CN5.20, CN6.20, J2.2, J10.14 (-12V), U15.2 (VI)
/A1: CN1.29, U7.3 (A1)
/A2: CN1.27, U7.5 (A3)
/A3: CN1.26, U7.6 (A4)
/A4: CN1.24, U7.7 (A5)
/A5: CN1.21, U7.9 (A7)
/A6: CN1.23, U7.8 (A6)
/A7: CN1.28, U7.4 (A2)
/A8: CN1.30, U7.2 (A0)
/A9: CN1.32, U6.9 (A7)
/A10: CN1.34, U6.8 (A6)
/A11: CN1.36, U6.7 (A5)
/A12: CN1.38, U6.6 (A4)
/A13: CN1.39, U6.5 (A3)
/A14: CN1.41, U6.4 (A2)
/A15: CN1.43, U6.3 (A1)
/A16: CN1.45, U6.2 (A0)
/A17: CN1.47, U5.8 (A6)
/A18: CN1.52, U5.7 (A5)
/A19: CN1.54, U5.6 (A4)
/A20: CN1.56, U5.5 (A3)
/A21: CN1.58, U5.3 (A1)
/A22: CN1.57, U5.4 (A2)
/A23: CN1.59, U5.2 (A0)
/D0: CN1.75, RN6.2 (R2.1), U4.4 (A2)
/D1: CN1.77, RN6.4 (R4.1), U4.2 (A0)
/D2: CN1.79, RN3.2 (R2.1), U3.8 (A6)
/D3: CN1.81, RN3.4 (R4.1), U3.6 (A4)
/D4: CN1.83, RN5.2 (R2.1), U3.4 (A2)
/D5: CN1.86, RN5.4 (R4.1), U3.2 (A0)
/D6: CN1.84, RN5.3 (R3.1), U3.3 (A1)
/D7: CN1.82, RN5.1 (R1.1), U3.5 (A3)
/D8: CN1.80, RN3.3 (R3.1), U3.7 (A5)
/D9: CN1.78, RN3.1 (R1.1), U3.9 (A7)
/D10: CN1.76, RN6.3 (R3.1), U4.3 (A1)
/D11: CN1.71, RN6.1 (R1.1), U4.5 (A3)
/D12: CN1.69, RN4.4 (R4.1), U4.6 (A4)
/D13: CN1.67, RN4.3 (R3.1), U4.7 (A5)
/D14: CN1.65, RN4.2 (R2.1), U4.8 (A6)
/D15: CN1.63, RN4.1 (R1.1), U4.9 (A7)
/TCK: J7.4, U1.30 (TCK)
/TDI: J7.2, U1.28 (TDI)
/TDO: J7.3, U1.53 (TDO)
/TMS: J7.1, U1.29 (TMS)
BA1: CN2.29, CN3.29, CN4.29, CN5.29, CN6.29, CN9.4 (R4.1), U7.17 (B1)
BA2: CN2.27, CN3.27, CN4.27, CN5.27, CN6.27, CN8.2 (R2.1), U7.15 (B3)
BA3: CN2.26, CN3.26, CN4.26, CN5.26, CN6.26, CN8.3 (R3.1), U7.14 (B4)
BA4: CN2.24, CN3.24, CN4.24, CN5.24, CN6.24, CN8.4 (R4.1), U7.13 (B5)
BA5: CN2.21, CN3.21, CN4.21, CN5.21, CN6.21, CN7.4 (R4.1), U7.11 (B7)
BA6: CN2.23, CN3.23, CN4.23, CN5.23, CN6.23, CN7.3 (R3.1), U7.12 (B6)
BA7: CN2.28, CN3.28, CN4.28, CN5.28, CN6.28, CN8.1 (R1.1), U7.16 (B2)
BA8: CN2.30, CN3.30, CN4.30, CN5.30, CN6.30, CN9.3 (R3.1), U7.18 (B0)
BA9: CN2.32, CN3.32, CN4.32, CN5.32, CN6.32, CN9.1 (R1.1), U6.11 (B7)
BA10: CN2.34, CN3.34, CN4.34, CN5.34, CN6.34, CN11.3 (R3.1), U6.12 (B6)
BA11: CN2.36, CN3.36, CN4.36, CN5.36, CN6.36, CN11.1 (R1.1), U6.13 (B5)
BA12: CN2.38, CN3.38, CN4.38, CN5.38, CN6.38, CN13.4 (R4.1), U6.14 (B4)
BA13: CN2.39, CN3.39, CN4.39, CN5.39, CN6.39, CN13.3 (R3.1), U6.15 (B3)
BA14: CN2.41, CN3.41, CN4.41, CN5.41, CN6.41, CN13.2 (R2.1), U6.16 (B2)
BA15: CN2.43, CN3.43, CN4.43, CN5.43, CN6.43, CN13.1 (R1.1), U6.17 (B1)
BA16: CN2.45, CN3.45, CN4.45, CN5.45, CN6.45, CN15.4 (R4.1), U6.18 (B0)
BA17: CN2.47, CN3.47, CN4.47, CN5.47, CN6.47, CN15.3 (R3.1), U5.12 (B6)
BA18: CN2.52, CN3.52, CN4.52, CN5.52, CN6.52, CN15.2 (R2.1), U5.13 (B5)
BA19: CN2.54, CN3.54, CN4.54, CN5.54, CN6.54, CN15.1 (R1.1), U1.42, U5.14 (B4)
BA20: CN2.56, CN3.56, CN4.56, CN5.56, CN6.56, CN17.4 (R4.1), U1.43, U5.15 (B3)
BA21: CN2.58, CN3.58, CN4.58, CN5.58, CN6.58, CN17.2 (R2.1), U1.44, U5.17 (B1)
BA22: CN2.57, CN3.57, CN4.57, CN5.57, CN6.57, CN17.3 (R3.1), U1.45, U5.16 (B2)
BA23: CN2.59, CN3.59, CN4.59, CN5.59, CN6.59, CN17.1 (R1.1), U1.46, U5.18 (B0)
BD0: CN2.75, CN3.75, CN4.75, CN5.75, CN6.75, CN14.3 (R3.1), U4.16 (B2)
BD1: CN2.77, CN3.77, CN4.77, CN5.77, CN6.77, CN14.1 (R1.1), U4.18 (B0)
BD2: CN2.79, CN3.79, CN4.79, CN5.79, CN6.79, CN12.3 (R3.1), U3.12 (B6)
BD3: CN2.81, CN3.81, CN4.81, CN5.81, CN6.81, CN12.1 (R1.1), U3.14 (B4)
BD4: CN2.83, CN3.83, CN4.83, CN5.83, CN6.83, CN10.2 (R2.1), U3.16 (B2)
BD5: CN2.86, CN3.86, CN4.86, CN5.86, CN6.86, CN10.1 (R1.1), U3.18 (B0)
BD6: CN2.84, CN3.84, CN4.84, CN5.84, CN6.84, CN10.3 (R3.1), U3.17 (B1)
BD7: CN2.82, CN3.82, CN4.82, CN5.82, CN6.82, CN10.4 (R4.1), U3.15 (B3)
BD8: CN2.80, CN3.80, CN4.80, CN5.80, CN6.80, CN12.2 (R2.1), U3.13 (B5)
BD9: CN2.78, CN3.78, CN4.78, CN5.78, CN6.78, CN12.4 (R4.1), U3.11 (B7)
BD10: CN2.76, CN3.76, CN4.76, CN5.76, CN6.76, CN14.2 (R2.1), U4.17 (B1)
BD11: CN2.71, CN3.71, CN4.71, CN5.71, CN6.71, CN14.4 (R4.1), U4.15 (B3)
BD12: CN2.69, CN3.69, CN4.69, CN5.69, CN6.69, CN16.1 (R1.1), U4.14 (B4)
BD13: CN2.67, CN3.67, CN4.67, CN5.67, CN6.67, CN16.2 (R2.1), U4.13 (B5)
BD14: CN2.65, CN3.65, CN4.65, CN5.65, CN6.65, CN16.3 (R3.1), U4.12 (B6)
BD15: CN2.63, CN3.63, CN4.63, CN5.63, CN6.63, CN16.4 (R4.1), U4.11 (B7)
BFC0: CN2.31, CN3.31, CN4.31, CN5.31, CN6.31, CN9.2 (R2.1), RN2.8 (R1.2), U2.11 (B7)
BFC1: CN2.33, CN3.33, CN4.33, CN5.33, CN6.33, CN11.4 (R4.1), RN2.7 (R2.2), U2.12 (B6)
BFC2: CN2.35, CN3.35, CN4.35, CN5.35, CN6.35, CN11.2 (R2.1), RN2.6 (R3.2), U2.13 (B5)
CDAC: CN1.15, CN2.15, CN3.15, CN4.15, CN5.15, CN6.15, U1.23
CFG500: CN2.12, J9.1, R17.1, U9.1
CPLD-7MHz: J1.3, U1.1
DMAOUT: U2.1 (A->B), U5.1 (A->B), U6.1 (A->B), U7.1 (A->B), U8.11
DOE: CN2.93, CN3.93, CN4.93, CN5.93, CN6.93, R12.2, R16.2
E: CN1.50, CN2.50, CN3.50, CN4.50, CN5.50, CN6.50
E7M: CN2.92, CN3.92, CN4.92, CN5.92, CN6.92, R4.2
FC0: CN1.31, U2.9 (A7)
FC1: CN1.33, U2.8 (A6)
FC2: CN1.35, U2.7 (A5)
GND: C1.1, C2.2, C3.1, C4.1, C5.2, C6.1, C7.2, C8.2, C9.2, C10.2, C11.2, C12.2, C13.2, C14.2, C15.2, C16.2, C17.1, C18.2, C19.2, C20.2, C21.2, C22.1, C25.2, C26.2, C30.1, C35.1, C36.1, C37.2, C38.1, C39.2, C40.2, C41.2, C42.1, C43.2, CN1.1, CN1.2, CN1.3, CN1.4, CN1.13, CN1.25, CN1.37, CN1.49, CN1.61, CN1.73, CN1.85, CN2.1, CN2.2, CN2.3, CN2.4, CN2.13, CN2.25, CN2.37, CN2.49, CN2.61, CN2.73, CN2.85, CN2.87, CN2.88, CN2.89, CN2.90, CN2.91, CN2.99, CN2.100, CN3.1, CN3.2, CN3.3, CN3.4, CN3.13, CN3.25, CN3.37, CN3.49, CN3.61, CN3.73, CN3.85, CN3.87, CN3.88, CN3.89, CN3.90, CN3.91, CN3.99, CN3.100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
unnamed: CN2.11, R1.1, U9.2
unnamed: CN2.14, CN3.14, CN4.14, CN5.14, CN6.14, FB1.2
unnamed: CN2.97, CN3.97, CN4.97, CN5.97, CN6.97
unnamed: CN2.98, CN3.98, CN4.98, CN5.98, CN6.98
unnamed: CN3.11, R2.1, U9.5
unnamed: CN3.12, U9.3, U9.4
unnamed: CN4.11, R5.1, U9.10
unnamed: CN4.12, U9.6, U9.9
unnamed: CN5.11, R6.1, U9.13
unnamed: CN5.12, U9.8, U9.12
unnamed: CN6.12, U9.11
unnamed: CN7.8 (R1.2), RN8.1 (R1.1)
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

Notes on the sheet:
BD7
BA15
_CFGOUT2
BA21
BA8
BD6
BD12
BFC1
BA16
BA13
BD1
_CFGIN4
AUTOCONFIG
_CFGIN5
BD10
BA18
_CFGIN1
BA5
OTHER BUFFER
SPARE
BA3
BA17
REMOTE SIGNALS
POWER GOOD
Push button
BA9
BA1
BD4
BA7
ZORRO
A2000 video slot
BFC0
BFC2
BA6
RESET
BA22
_CFGOUT3
_CFGIN2
BA23
BD0

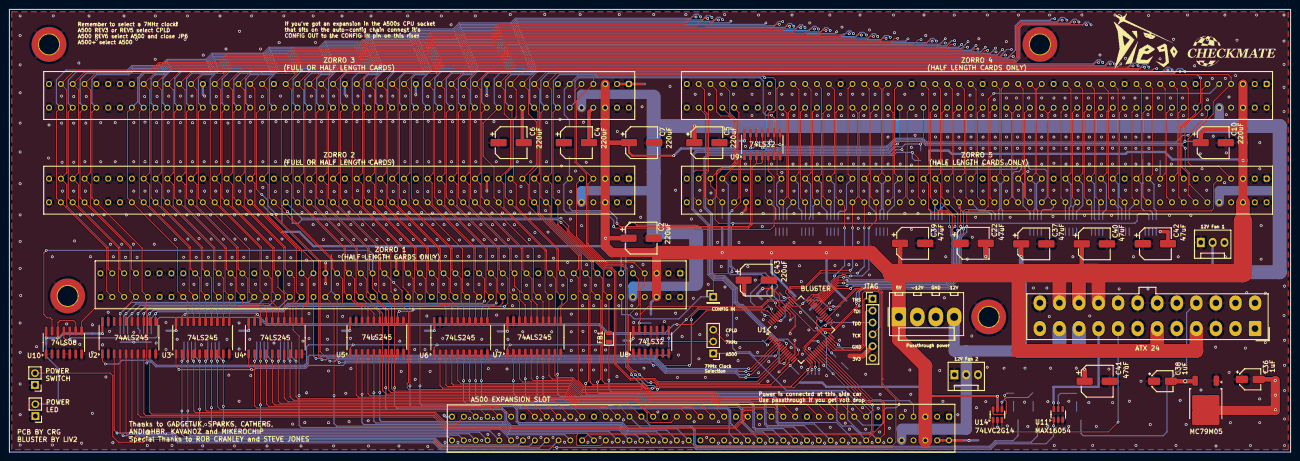
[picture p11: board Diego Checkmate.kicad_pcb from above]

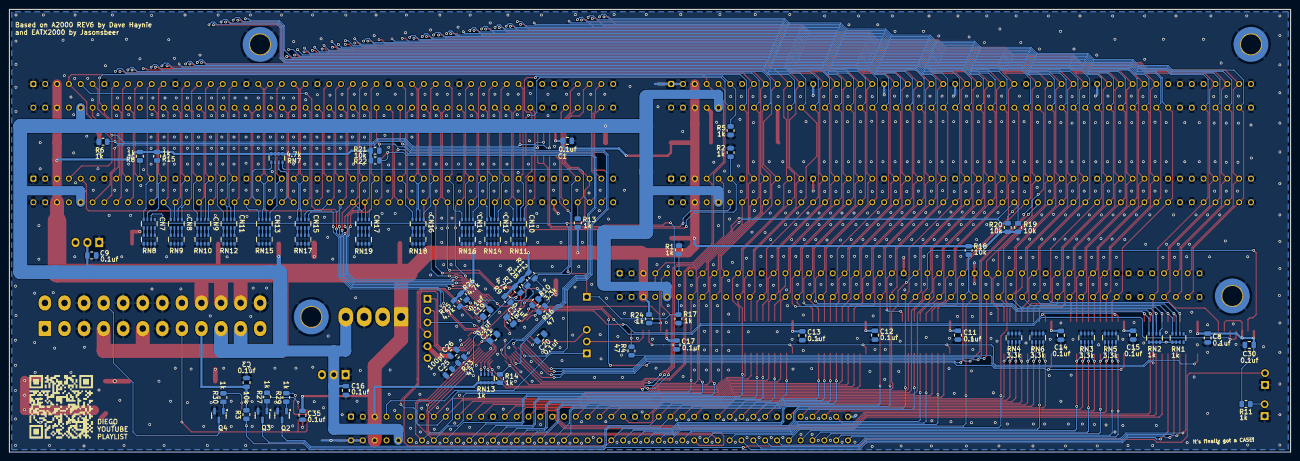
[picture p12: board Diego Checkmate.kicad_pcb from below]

Board: 4 copper layers, 275.0 x 95.0 mm, 130 parts (82 on the bottom side), 223 nets.

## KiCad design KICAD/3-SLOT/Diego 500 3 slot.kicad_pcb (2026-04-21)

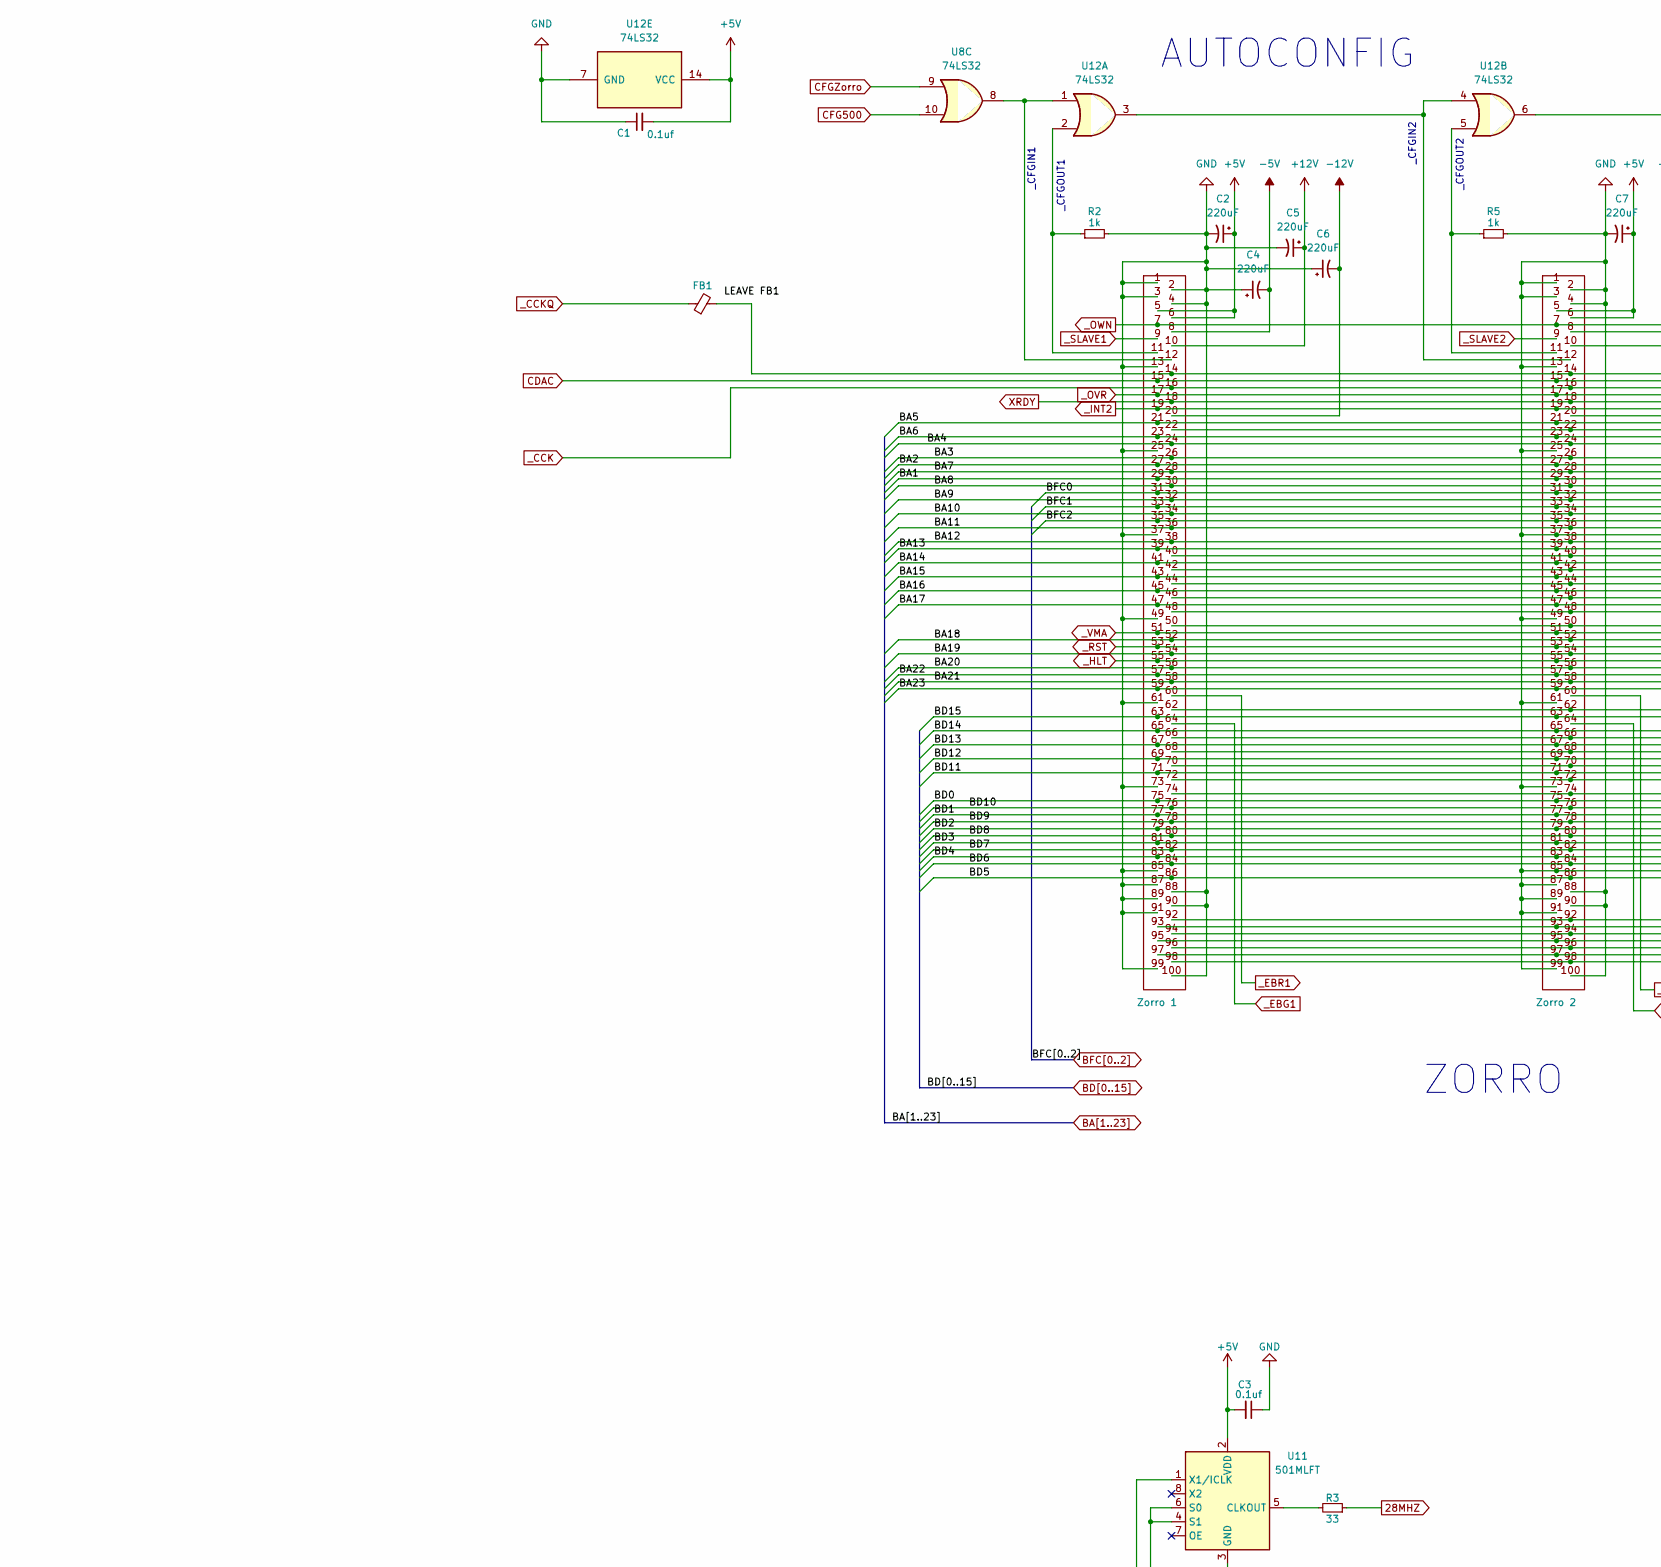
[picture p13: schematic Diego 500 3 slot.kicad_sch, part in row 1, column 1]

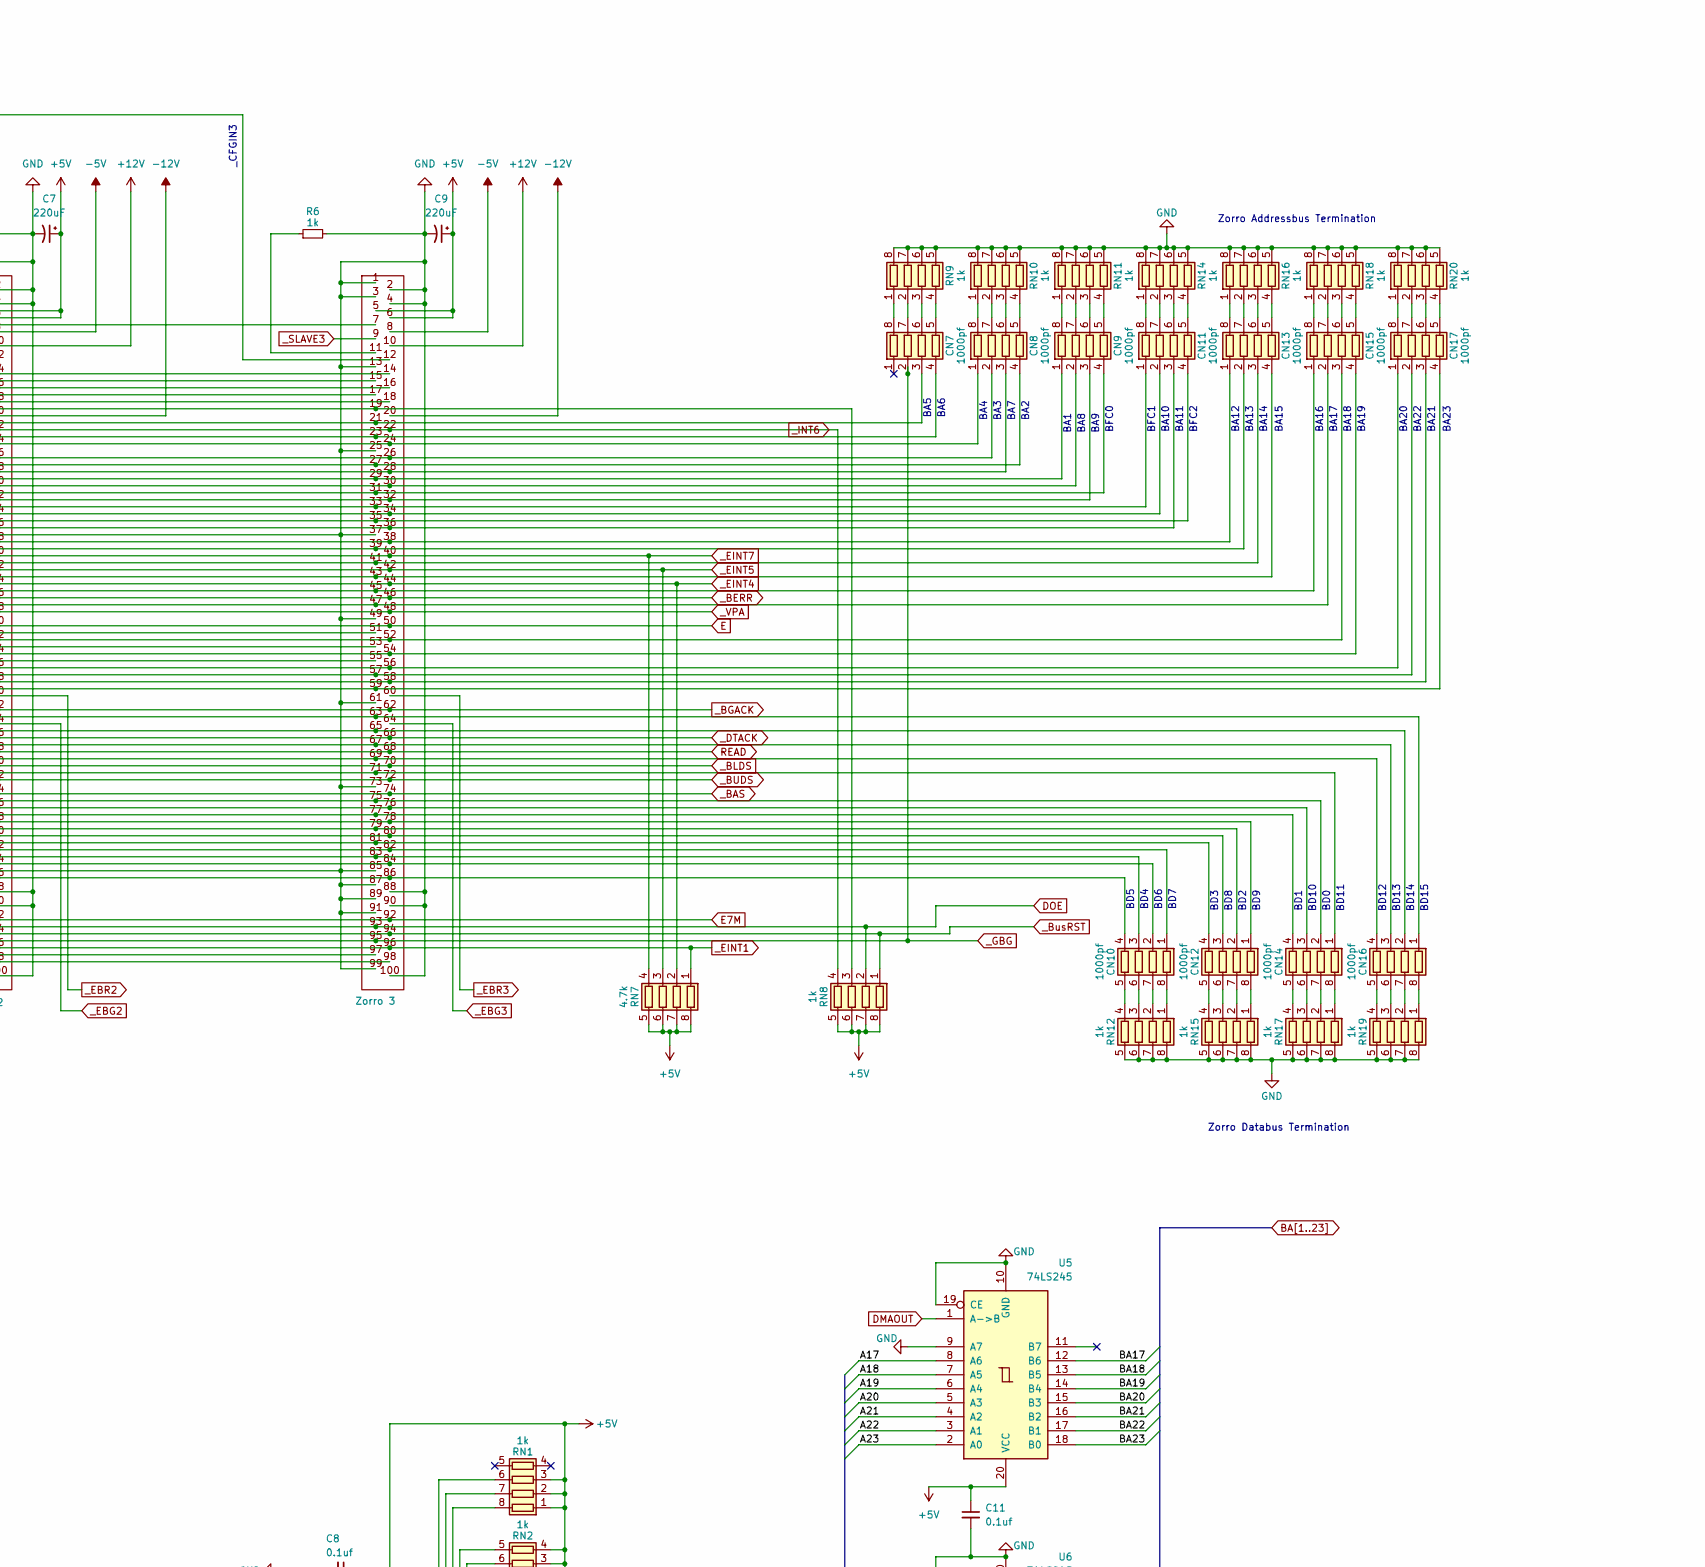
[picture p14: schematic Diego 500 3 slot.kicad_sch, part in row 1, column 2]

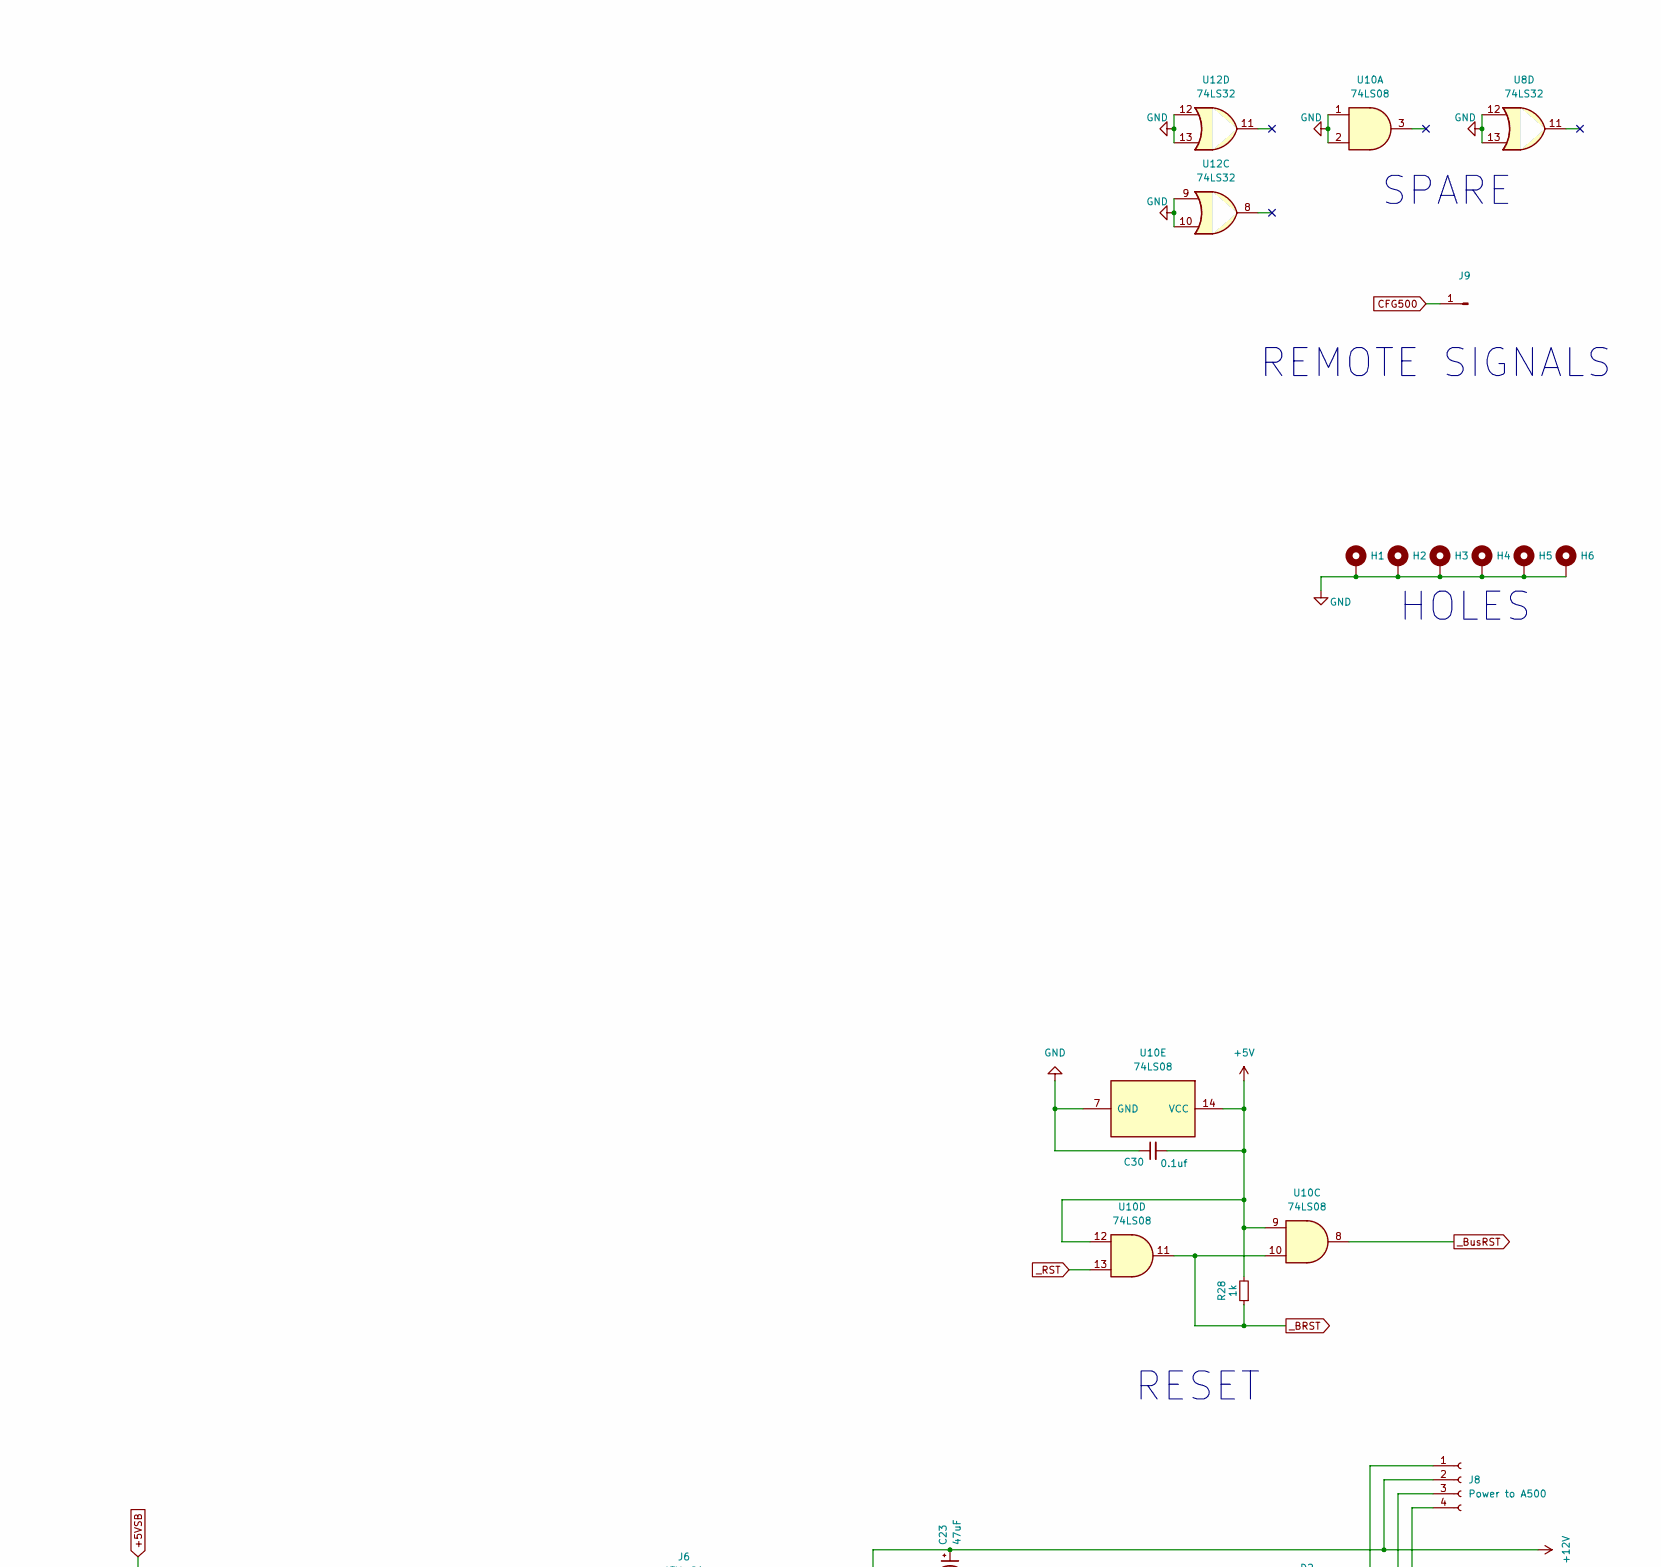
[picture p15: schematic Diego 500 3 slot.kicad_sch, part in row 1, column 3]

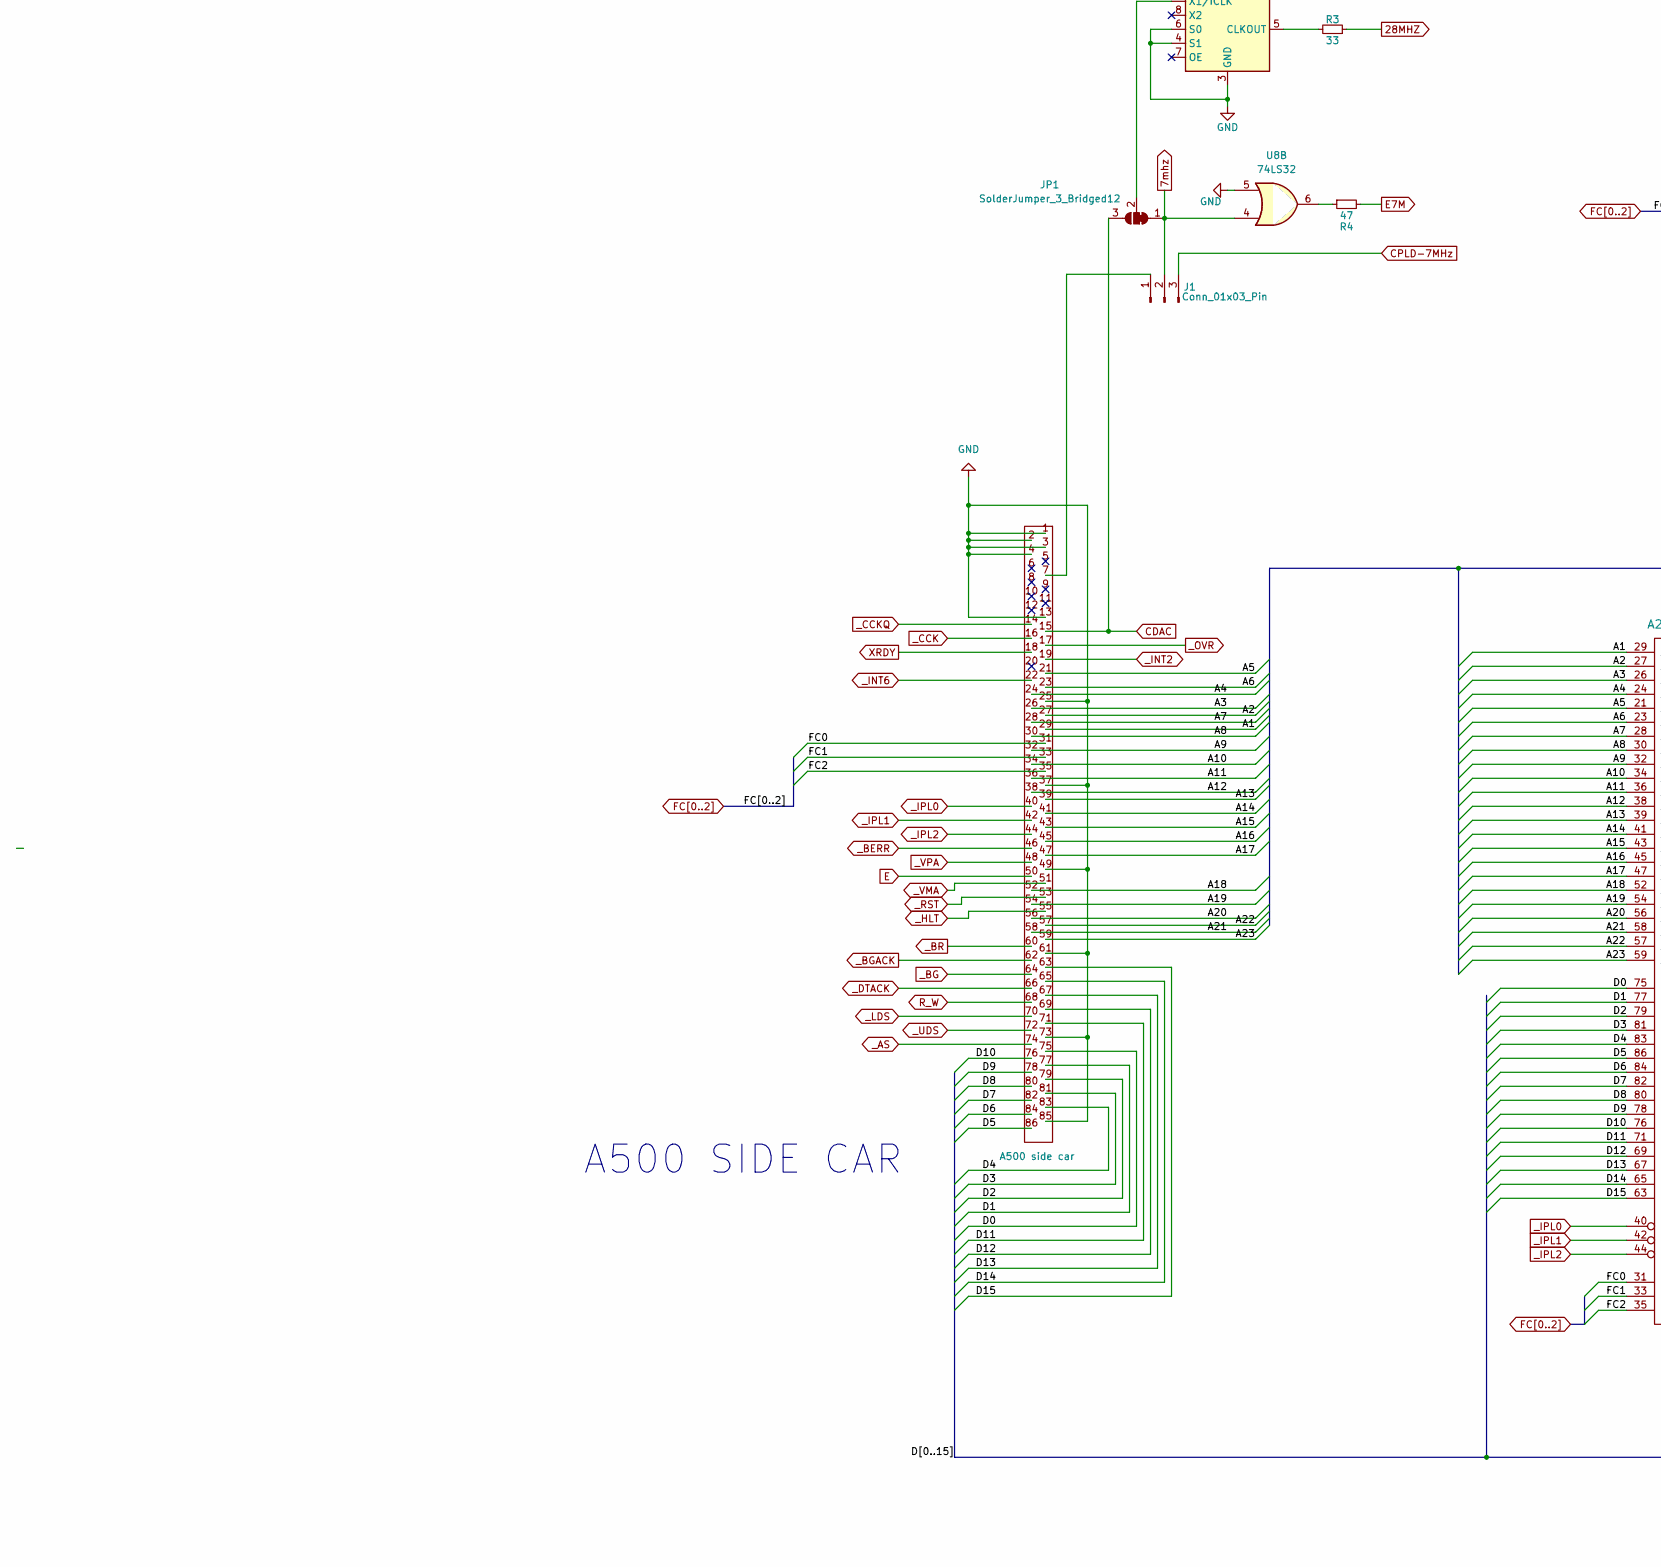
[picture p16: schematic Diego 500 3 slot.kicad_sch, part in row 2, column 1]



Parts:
C1, C3, C8, C11, C12, C13, C14, C15, C17, C30, C33: 0.1uf; C_0805_2012Metric; LCSC C49678
C2, C4, C5, C6, C7, C9, C34: 220uF; CP_Elec_6.3x7.7; LCSC C278407
C18, C19, C20, C21: 0.1uf; C_0805_2012Metric_Pad1.18x1.45mm_HandSolder; LCSC C49678
C22, C24: 1uF; CP_Elec_4x5.4; LCSC C3348
C23, C27, C28, C29, C31, C32: 47uF; CP_Elec_6.3x7.7; LCSC C336249
C25, C26: 100pf; C_0805_2012Metric; LCSC C1790
CN1: A500 side car; A500_SIDE_CONNECTOR
CN2: Zorro 1; Samtec_HLE-150-02-xx-DV-TE_2x50_P2.54mm_Horizontal
CN3: Zorro 2; Samtec_HLE-150-02-xx-DV-TE_2x50_P2.54mm_Horizontal
CN4: Zorro 3; Samtec_HLE-150-02-xx-DV-TE_2x50_P2.54mm_Horizontal
CN7, CN8, CN9, CN10, CN11, CN12, CN13, CN14, CN15, CN16, CN17: 1000pf; R_Array_Convex_4x0603; LCSC C541606
D1: LED; LED_1206_3216Metric_Pad1.42x1.75mm_HandSolder; LCSC C49018
D2: LED; LED_1206_3216Metric_Pad1.42x1.75mm_HandSolder; LCSC C14641
FB1: FerriteBead_Small; D_0805_2012Metric; LCSC C1015
H1, H2, H3, H4, H5, H6: MountingHole_Pad; MountingHole_3.2mm_M3_DIN965_Pad
J1: Conn_01x03_Pin; PinHeader_1x03_P2.54mm_Vertical
J2: A2000_CPUSLOT_EDGE_LOGICAL; Samtec_HLE-150-02-xx-DV-TE_2x43_P2.54mm_Horizontal
J3: HDD 2; PinHeader_1x02_P2.54mm_Vertical
J4: HDD 1; PinHeader_1x02_P2.54mm_Vertical
J5: Conn_01x02_Pin; PinHeader_1x02_P2.54mm_Vertical
J6: ATX-24; Molex_Mini-Fit_Jr_5569-24A2_2x12_P4.20mm_Horizontal
J7: Buster; PinHeader_1x06_P2.54mm_Vertical
J8: Power to A500; Molex_Mini-Fit_Jr_5569-04A2_2x02_P4.20mm_Horizontal
J9: Conn_01x01_Pin; PinHeader_1x01_P2.54mm_Vertical
JP1: SolderJumper_3_Bridged12; SolderJumper-3_P1.3mm_Bridged12_RoundedPad1.0x1.5mm
Q1: S8050; SOT-23; LCSC C2146
R1, R2, R5, R6, R14, R17, R24, R28, R29: 1k; R_0805_2012Metric; LCSC C17513
R3: 33; R_0805_2012Metric; LCSC C17634
R4, R16, R23: 47; R_0805_2012Metric; LCSC C17714
R7, R9, R25, R26: 4.7k; R_0805_2012Metric; LCSC C17673
R10: 3.3k; R_0805_2012Metric; LCSC C26010
R11, R12, R13, R18, R19, R20, R21, R22: 10k; R_0805_2012Metric; LCSC C17414
R15: 680; R_0805_2012Metric; LCSC C17798
R27: 1k; R_0805_2012Metric; LCSC C17798
RN1, RN2, RN8, RN9, RN10, RN11, RN12, RN13, RN14, RN15, RN16, RN17, RN18, RN19, RN20: 1k; R_Array_Convex_4x0603; LCSC C20197
RN3, RN4, RN5, RN6: 3.3k; R_Array_Convex_4x0603; LCSC C102665
RN7: 4.7k; R_Array_Convex_4x0603; LCSC C66697
SW1: SW_Push; SW_PUSH_1P1T_6x3.5mm_H4.3_APEM_MJTP1243
U1: BLUSTER; TQFP-64_10x10mm_P0.5mm; LCSC C90569
U2, U7: 74ALS245; SO-20_5.3x12.6mm_P1.27mm; LCSC C2675885
U3, U4, U5, U6: 74LS245; SO-20_5.3x12.6mm_P1.27mm; LCSC C7753
U8, U12: 74LS32; SO-14_3.9x8.65mm_P1.27mm; LCSC C116812
U9: MAX16054AZT_T; SOT95P275X110-6N; LCSC C79401
U10: 74LS08; SO-14_3.9x8.65mm_P1.27mm; LCSC C6802
U11: 501MLFT; SOIC-8_3.9x4.9mm_P1.27mm; LCSC C2651221
U13: MC79M05; TO-252-2; LCSC C126401

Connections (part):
7mhz: J1.2, J2.7 (exp), JP1.1 (A), U8.4
28MHZ: J2.9 (28MHz), R3.1
+3V3: C18.1, C19.1, C20.1, C21.1, C31.1, C34.1, J6.1 (+3.3V), J6.2 (+3.3V), J6.12 (+3.3V), J6.13 (+3.3V), J7.6, U1.3 (VCC), U1.26 (VCCIO), U1.37 (VCC), U1.55 (VCCIO)
+5V: C1.2, C2.1, C3.2, C7.1, C8.1, C9.1, C11.1, C12.1, C13.1, C14.1, C15.1, C27.1, C28.1, C29.1, C30.2, C33.2, CN2.5, CN2.6, CN3.5, CN3.6, CN4.5, CN4.6, J2.5 (+5V), J2.6 (+5V), J6.4 (+5V), J6.6 (+5V), J6.21 (+5V), J6.22 (+5V), J6.23 (+5V), J8.1, R7.1, R9.2, R11.2, R12.2, R14.1, R15.2, R18.1, R19.1, R20.1, R21.1, R22.1, R24.1, R25.1, R26.1, R27.2, R28.2, RN1.1 (R1.1), RN1.2 (R2.1), RN1.3 (R3.1), RN2.1 (R1.1), RN2.2 (R2.1), RN2.3 (R3.1), RN2.4 (R4.1), RN7.5 (R4.2), RN7.6 (R3.2), RN7.7 (R2.2), RN7.8 (R1.2), RN8.5 (R4.2), RN8.6 (R3.2), RN8.7 (R2.2), RN8.8 (R1.2), RN13.1 (R1.1), RN13.2 (R2.1), RN13.3 (R3.1), RN13.4 (R4.1), U2.20 (VCC), U3.20 (VCC), U4.20 (VCC), U5.20 (VCC), U6.20 (VCC), U7.20 (VCC), U8.14 (VCC), U10.9, U10.12, U10.14 (VCC), U11.2 (VDD), U12.14 (VCC); also elsewhere on the board
+5VSB: C17.2, J6.9 (+5VSB), R13.1, U9.6 (VCC)
+12V: C5.1, C23.1, CN2.10, CN3.10, CN4.10, J2.10 (+12V), J6.10 (+12V), J6.11 (+12V), J8.2
-5V: C4.2, C24.2, CN2.8, CN3.8, CN4.8, J2.8 (-5V), U13.3 (VO)
-12V: C6.2, C22.2, C32.2, CN2.20, CN3.20, CN4.20, J6.14 (-12V), J8.3, U13.2 (VI)
/A1: CN1.29, J2.29 (A1), U7.2 (A0)
/A2: CN1.27, J2.27 (A2), U7.4 (A2)
/A3: CN1.26, J2.26 (A3), U7.6 (A4)
/A4: CN1.24, J2.24 (A4), U7.8 (A6)
/A5: CN1.21, J2.21 (A5), U7.9 (A7)
/A6: CN1.23, J2.23 (A6), U7.7 (A5)
/A7: CN1.28, J2.28 (A7), U7.5 (A3)
/A8: CN1.30, J2.30 (A8), U7.3 (A1)
/A9: CN1.32, J2.32 (A9), U6.9 (A7)
/A10: CN1.34, J2.34 (A10), U6.8 (A6)
/A11: CN1.36, J2.36 (A11), U6.7 (A5)
/A12: CN1.38, J2.38 (A12), U6.6 (A4)
/A13: CN1.39, J2.39 (A13), U6.5 (A3)
/A14: CN1.41, J2.41 (A14), U6.4 (A2)
/A15: CN1.43, J2.43 (A15), U6.3 (A1)
/A16: CN1.45, J2.45 (A16), U6.2 (A0)
/A17: CN1.47, J2.47 (A17), U5.8 (A6)
/A18: CN1.52, J2.52 (A18), U5.7 (A5)
/A19: CN1.54, J2.54 (A19), U5.6 (A4)
/A20: CN1.56, J2.56 (A20), U5.5 (A3)
/A21: CN1.58, J2.58 (A21), U5.4 (A2)
/A22: CN1.57, J2.57 (A22), U5.3 (A1)
/A23: CN1.59, J2.59 (A23), U5.2 (A0)
/D0: CN1.75, J2.75 (PD0), RN6.3 (R3.1), U4.3 (A1)
/D1: CN1.77, J2.77 (PD1), RN6.4 (R4.1), U4.2 (A0)
/D2: CN1.79, J2.79 (PD2), RN3.2 (R2.1), U3.8 (A6)
/D3: CN1.81, J2.81 (PD3), RN3.4 (R4.1), U3.6 (A4)
/D4: CN1.83, J2.83 (PD4), RN5.2 (R2.1), U3.4 (A2)
/D5: CN1.86, J2.86 (PD5), RN5.4 (R4.1), U3.2 (A0)
/D6: CN1.84, J2.84 (PD6), RN5.3 (R3.1), U3.3 (A1)
/D7: CN1.82, J2.82 (PD7), RN5.1 (R1.1), U3.5 (A3)
/D8: CN1.80, J2.80 (PD8), RN3.3 (R3.1), U3.7 (A5)
/D9: CN1.78, J2.78 (PD9), RN3.1 (R1.1), U3.9 (A7)
/D10: CN1.76, J2.76 (PD10), RN6.2 (R2.1), U4.4 (A2)
/D11: CN1.71, J2.71 (PD11), RN6.1 (R1.1), U4.5 (A3)
/D12: CN1.69, J2.69 (PD12), RN4.4 (R4.1), U4.6 (A4)
/D13: CN1.67, J2.67 (PD13), RN4.3 (R3.1), U4.7 (A5)
/D14: CN1.65, J2.65 (PD14), RN4.2 (R2.1), U4.8 (A6)
/D15: CN1.63, J2.63 (PD15), RN4.1 (R1.1), U4.9 (A7)
/TCK: J7.4, U1.30 (TCK)
/TDI: J7.2, U1.28 (TDI)
/TDO: J7.3, U1.53 (TDO)
/TMS: J7.1, U1.29 (TMS)
BA1: CN2.29, CN3.29, CN4.29, CN9.1 (R1.1), U7.18 (B0)
BA2: CN2.27, CN3.27, CN4.27, CN8.4 (R4.1), U7.16 (B2)
BA3: CN2.26, CN3.26, CN4.26, CN8.2 (R2.1), U7.14 (B4)
BA4: CN2.24, CN3.24, CN4.24, CN8.1 (R1.1), U7.12 (B6)
BA5: CN2.21, CN3.21, CN4.21, CN7.3 (R3.1), U7.11 (B7)
BA6: CN2.23, CN3.23, CN4.23, CN7.4 (R4.1), U7.13 (B5)
BA7: CN2.28, CN3.28, CN4.28, CN8.3 (R3.1), U7.15 (B3)
BA8: CN2.30, CN3.30, CN4.30, CN9.2 (R2.1), U7.17 (B1)
BA9: CN2.32, CN3.32, CN4.32, CN9.3 (R3.1), U6.11 (B7)
BA10: CN2.34, CN3.34, CN4.34, CN11.2 (R2.1), U6.12 (B6)
BA11: CN2.36, CN3.36, CN4.36, CN11.3 (R3.1), U6.13 (B5)
BA12: CN2.38, CN3.38, CN4.38, CN13.1 (R1.1), U6.14 (B4)
BA13: CN2.39, CN3.39, CN4.39, CN13.2 (R2.1), U6.15 (B3)
BA14: CN2.41, CN3.41, CN4.41, CN13.3 (R3.1), U6.16 (B2)
BA15: CN2.43, CN3.43, CN4.43, CN13.4 (R4.1), U6.17 (B1)
BA16: CN2.45, CN3.45, CN4.45, CN15.1 (R1.1), U6.18 (B0)
BA17: CN2.47, CN3.47, CN4.47, CN15.2 (R2.1), U5.12 (B6)
BA18: CN2.52, CN3.52, CN4.52, CN15.3 (R3.1), U5.13 (B5)
BA19: CN2.54, CN3.54, CN4.54, CN15.4 (R4.1), U1.42, U5.14 (B4)
BA20: CN2.56, CN3.56, CN4.56, CN17.1 (R1.1), U1.43, U5.15 (B3)
BA21: CN2.58, CN3.58, CN4.58, CN17.3 (R3.1), U1.44, U5.16 (B2)
BA22: CN2.57, CN3.57, CN4.57, CN17.2 (R2.1), U1.45, U5.17 (B1)
BA23: CN2.59, CN3.59, CN4.59, CN17.4 (R4.1), U1.46, U5.18 (B0)
BD0: CN2.75, CN3.75, CN4.75, CN14.2 (R2.1), U4.17 (B1)
BD1: CN2.77, CN3.77, CN4.77, CN14.4 (R4.1), U4.18 (B0)
BD2: CN2.79, CN3.79, CN4.79, CN12.2 (R2.1), U3.12 (B6)
BD3: CN2.81, CN3.81, CN4.81, CN12.4 (R4.1), U3.14 (B4)
BD4: CN2.83, CN3.83, CN4.83, CN10.3 (R3.1), U3.16 (B2)
BD5: CN2.86, CN3.86, CN4.86, CN10.4 (R4.1), U3.18 (B0)
BD6: CN2.84, CN3.84, CN4.84, CN10.2 (R2.1), U3.17 (B1)
BD7: CN2.82, CN3.82, CN4.82, CN10.1 (R1.1), U3.15 (B3)
BD8: CN2.80, CN3.80, CN4.80, CN12.3 (R3.1), U3.13 (B5)
BD9: CN2.78, CN3.78, CN4.78, CN12.1 (R1.1), U3.11 (B7)
BD10: CN2.76, CN3.76, CN4.76, CN14.3 (R3.1), U4.16 (B2)
BD11: CN2.71, CN3.71, CN4.71, CN14.1 (R1.1), U4.15 (B3)
BD12: CN2.69, CN3.69, CN4.69, CN16.4 (R4.1), U4.14 (B4)
BD13: CN2.67, CN3.67, CN4.67, CN16.3 (R3.1), U4.13 (B5)
BD14: CN2.65, CN3.65, CN4.65, CN16.2 (R2.1), U4.12 (B6)
BD15: CN2.63, CN3.63, CN4.63, CN16.1 (R1.1), U4.11 (B7)
BFC0: CN2.31, CN3.31, CN4.31, CN9.4 (R4.1), RN2.8 (R1.2), U2.11 (B7)
BFC1: CN2.33, CN3.33, CN4.33, CN11.1 (R1.1), RN2.7 (R2.2), U2.12 (B6)
BFC2: CN2.35, CN3.35, CN4.35, CN11.4 (R4.1), RN2.6 (R3.2), U2.13 (B5)
CDAC: CN1.15, CN2.15, CN3.15, CN4.15, J2.15 (CDAC), JP1.3 (B), U1.23
CFG500: J2.12 (CONFIG), J9.1, R29.1, U8.10
CFGZorro: J2.11 (COPFG), R1.1, U8.9
CPLD-7MHz: J1.3, U1.1
DMAOUT: U2.1 (A->B), U5.1 (A->B), U6.1 (A->B), U7.1 (A->B), U8.3
DOE: CN2.93, CN3.93, CN4.93, R16.2, RN8.2 (R2.1); also elsewhere on the board
E: CN1.50, CN2.50, CN3.50, CN4.50, J2.50 (E)
E7M: CN2.92, CN3.92, CN4.92, R4.2
FC0: CN1.31, J2.31 (FC0), U2.9 (A7)
FC1: CN1.33, J2.33 (FC1), U2.8 (A6)
FC2: CN1.35, J2.35 (FC2), U2.7 (A5)
GND: C1.1, C2.2, C3.1, C4.1, C5.2, C6.1, C7.2, C8.2, C9.2, C11.2, C12.2, C13.2, C14.2, C15.2, C17.1, C18.2, C19.2, C20.2, C21.2, C22.1, C23.2, C24.1, C25.2, C26.2, C27.2, C28.2, C29.2, C30.1, C31.2, C32.1, C33.1, C34.2, CN1.1, CN1.2, CN1.3, CN1.4, CN1.13, CN1.25, CN1.37, CN1.49, CN1.61, CN1.73, CN1.85, CN2.1, CN2.2, CN2.3, CN2.4, CN2.13, CN2.25, CN2.37, CN2.49, CN2.61, CN2.73, CN2.85, CN2.87, CN2.88, CN2.89, CN2.90, CN2.91, CN2.99, CN2.100, CN3.1, CN3.2, CN3.3, CN3.4, CN3.13, CN3.25, CN3.37, CN3.49, CN3.61, CN3.73, CN3.85, CN3.87, CN3.88, CN3.89, CN3.90, CN3.91, CN3.99, CN3.100, CN4.1, CN4.2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
unnamed: CN2.11, R2.1, U12.2
unnamed: CN2.12, U8.8, U12.1
unnamed: CN2.14, CN3.14, CN4.14, FB1.2
unnamed: CN2.97, CN3.97, CN4.97
unnamed: CN2.98, CN3.98, CN4.98
unnamed: CN3.11, R5.1, U12.5
unnamed: CN3.12, U12.3, U12.4
unnamed: CN4.11, R6.1
unnamed: CN4.12, U12.6
unnamed: CN7.8 (R1.2), RN9.1 (R1.1)
unnamed: CN7.7 (R2.2), RN9.2 (R2.1)
unnamed: CN7.6 (R3.2), RN9.3 (R3.1)
unnamed: CN7.5 (R4.2), RN9.4 (R4.1)
unnamed: CN8.8 (R1.2), RN10.1 (R1.1)
unnamed: CN8.7 (R2.2), RN10.2 (R2.1)
unnamed: CN8.6 (R3.2), RN10.3 (R3.1)
unnamed: CN8.5 (R4.2), RN10.4 (R4.1)
unnamed: CN9.8 (R1.2), RN11.1 (R1.1)
unnamed: CN9.7 (R2.2), RN11.2 (R2.1)
unnamed: CN9.6 (R3.2), RN11.3 (R3.1)
unnamed: CN9.5 (R4.2), RN11.4 (R4.1)
unnamed: CN10.8 (R1.2), RN12.1 (R1.1)
unnamed: CN10.7 (R2.2), RN12.2 (R2.1)
unnamed: CN10.6 (R3.2), RN12.3 (R3.1)
unnamed: CN10.5 (R4.2), RN12.4 (R4.1)
unnamed: CN11.8 (R1.2), RN14.1 (R1.1)
unnamed: CN11.7 (R2.2), RN14.2 (R2.1)
unnamed: CN11.6 (R3.2), RN14.3 (R3.1)
unnamed: CN11.5 (R4.2), RN14.4 (R4.1)
unnamed: CN12.8 (R1.2), RN15.1 (R1.1)
unnamed: CN12.7 (R2.2), RN15.2 (R2.1)
unnamed: CN12.6 (R3.2), RN15.3 (R3.1)
unnamed: CN12.5 (R4.2), RN15.4 (R4.1)
unnamed: CN13.8 (R1.2), RN16.1 (R1.1)
unnamed: CN13.7 (R2.2), RN16.2 (R2.1)
unnamed: CN13.6 (R3.2), RN16.3 (R3.1)
unnamed: CN13.5 (R4.2), RN16.4 (R4.1)
unnamed: CN14.8 (R1.2), RN17.1 (R1.1)
unnamed: CN14.7 (R2.2), RN17.2 (R2.1)
unnamed: CN14.6 (R3.2), RN17.3 (R3.1)
unnamed: CN14.5 (R4.2), RN17.4 (R4.1)
unnamed: CN15.8 (R1.2), RN18.1 (R1.1)
unnamed: CN15.7 (R2.2), RN18.2 (R2.1)
unnamed: CN15.6 (R3.2), RN18.3 (R3.1)
unnamed: CN15.5 (R4.2), RN18.4 (R4.1)
unnamed: CN16.8 (R1.2), RN19.1 (R1.1)
unnamed: CN16.7 (R2.2), RN19.2 (R2.1)
unnamed: CN16.6 (R3.2), RN19.3 (R3.1)
unnamed: CN16.5 (R4.2), RN19.4 (R4.1)
unnamed: CN17.8 (R1.2), RN20.1 (R1.1)
unnamed: CN17.7 (R2.2), RN20.2 (R2.1)
unnamed: CN17.6 (R3.2), RN20.3 (R3.1)
unnamed: CN17.5 (R4.2), RN20.4 (R4.1)
unnamed: D1.2 (A), R15.1
unnamed: D1.1 (K), U10.6
unnamed: D2.2 (A), R27.1
unnamed: CN1.7, J1.1
unnamed: J3.1, R12.1, U10.4
unnamed: J4.1, R11.1, U10.5
unnamed: J5.1, R13.2, SW1.2, U9.1 (IN)
unnamed: J6.16 (PS_ON#), Q1.3 (C)
unnamed: JP1.2 (C), U11.1 (X1/ICLK)
unnamed: Q1.1 (B), R17.1
unnamed: R4.1, U8.6
unnamed: R23.1, U1.27
unnamed: R16.1, U1.62
unnamed: R17.2, U9.5 (OUT)
unnamed: R3.2, U11.5 (CLKOUT)
READ: CN2.68, CN3.68, CN4.68, RN2.5 (R4.2), U1.47, U2.14 (B4)
R_W: CN1.68, J2.68 (PRW), U2.6 (A4)
XRDY: CN1.18, CN2.18, CN3.18, CN4.18, J2.18 (XRDY)
_AS: CN1.74, J2.74 (AS), U2.3 (A1)
_BAS: CN2.74, CN3.74, CN4.74, RN1.6 (R3.2), U1.48, U2.17 (B1)
_BERR: CN1.46, CN2.46, CN3.46, CN4.46, J2.46 (BERR), U1.36
_BG: CN1.64, U1.22
_BGACK: CN1.62, CN2.62, CN3.62, CN4.62, J2.62 (BGACK)
_BLDS: CN2.70, CN3.70, CN4.70, RN1.8 (R1.2), U1.49, U2.15 (B3)
_BOSS: J2.20 (BOSS), R7.2, U1.51
_BR: CN1.60, U1.38
_BRST: R28.1, U1.57, U10.10, U10.11
_BUDS: CN2.72, CN3.72, CN4.72, RN1.7 (R2.2), U1.50, U2.16 (B2)
_BusRST: CN2.94, CN3.94, CN4.94, RN8.1 (R1.1), U10.8; also elsewhere on the board
_CBG: J2.64 (CBG), R26.2, U1.40
_CBR: J2.60 (CBR), R25.2, U1.39
_CCK: CN1.16, CN2.16, CN3.16, CN4.16, J2.16 (C1), U1.24
_CCKQ: CN1.14, FB1.1, J2.14 (C3), U1.25
_D2P: R10.1, U1.60, U3.1 (A->B), U4.1 (A->B)
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

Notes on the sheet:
_CFGIN2
BA11
Zorro Addressbus Termination
AUTOCONFIG
BA18
BD14
BD15
BD1
BD4
BD11
BD9
BD6
BA1
BA3
BD2
BA21
BD13
BA16
BA15
BD0
BA20
POWER
OTHER BUFFER
SPARE
BA8
BD7
BA2
HDD ACTIVITY
BFC0
REMOTE SIGNALS
BA23
BA5
BA22
BD8
BA4
A2000 video slot
RESET
BD5
BA6
BA9

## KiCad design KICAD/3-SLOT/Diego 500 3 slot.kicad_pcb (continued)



Board: 4 copper layers, 155.0 x 140.0 mm, 133 parts (82 on the bottom side), 225 nets.

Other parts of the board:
R38, R39, R40, R41: 1k; R_0805_2012Metric

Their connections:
+5V: R38.1, R39.1, R40.1, R41.1; also elsewhere on the board
DOE: R40.2; also elsewhere on the board
_BusRST: R41.2; also elsewhere on the board
_INT2: R38.2; also elsewhere on the board
_INT6: R39.2; also elsewhere on the board

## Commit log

2026-02-27 3 slot added
    [BOM-Diego 500 3 slot.csv, Diego 500 3 slot.kicad_pcb, Diego 500 3 slot.kicad_sch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]
2026-02-27 General update
    [Diego 500 3 slot.kicad_pcb]
2026-03-06 Fix autoconfig error
    [Diego 500 3 slot.kicad_pcb, Diego 500 3 slot.kicad_sch, Diego 500 5 slot.kicad_pcb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]
2026-03-06 Revise README for DIEGO 500
    Updated README to include project details and assembly instructions.
2026-04-21 KICAD and JLC files updated
    [BOM-Diego 500 3 slot.csv, BOM-Diego 500 5 slot.csv, Diego 500 3 slot.kicad_pcb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]
2026-04-23 Revise README for DIEGO 500 version 1.1
    Updated README to reflect version 1.1 changes, including ordering details, assembly instructions, and additional FAQs.
2026-04-27 Base 3D files added
    [Diego 500 3 slot base.stl, Diego 500 5 slot base.stl]
2026-04-27 Revise README for DIEGO 500 project
    Updated README to include additional details about the DIEGO 500 project, including assembly instructions, testing results, and licensing information.
2026-09-28 BOM updated
    [BOM-Diego 500 3 slot.csv, BOM-Diego 500 5 slot.csv, Diego 500 5 slot.kicad_sch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]
2026-09-28 Checkmate version added
    [BOM-Diego Checkmate.csv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]
2026-10-14 Revise README with project details and updates
    Updated README.md to add new information about the DIEGO project, including assembly instructions, testing results, and FAQs.
2026-10-14 New 3d printable base added
